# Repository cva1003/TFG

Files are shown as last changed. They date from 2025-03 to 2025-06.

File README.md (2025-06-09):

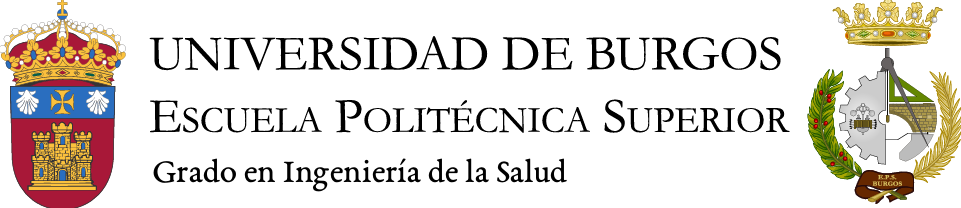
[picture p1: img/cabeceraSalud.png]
Cabecera grado

# Seguimiento clínico de pacientes con afectaciones en la mano con la ayuda de sensores de presión.
Trabajo de Fin de Grado del grado Ingeniería de la Salud de la Universidad de Burgos, realizado en el curso 2024/2025. 
A partir de este repositorio se puede observar el desarrollo del proyecto, así como los documentos con toda la información recabada y el código fuente.

## Resumen
Este proyecto se centra en la búsqueda de resolver un problema real, creando un prototipo de dispositivo e interfaz para cuantificar la fuerza que los pacientes pueden ejercer en las sesiones de terapia y establecer un registro a lo largo del tiempo de estas.

A pesar de que estos tipos de dispositivos ya existen, los hospitales públicos no están dotados de ellos debido a su alto precio y los escasos recursos en algunas áreas de los hospitales. La iniciativa de la creación de este proyecto, surge como respuesta a la necesidad comentada desde el área de terapia ocupacional. 

Se han estudiado los dispositivos que ya están en el mercado, para posteriormente realizar una búsqueda de los componentes más idóneos para el dispositivo a crear. Se ha creado un prototipo físico con sensores de fuerza resistivos y una interfaz básica para la visualización y registro de las cuantificaciones de fuerza.

### Autora: Claudia Valentín Alguacil.
### Tutor: Pedro Luis Sanchez Ortega.

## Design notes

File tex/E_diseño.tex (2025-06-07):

\apendice{Manual de especificación de diseño}
En esta sección, se detallan los planos y el diseño arquitectónico correspondientes con el desarrollo del prototipo.
\section{Planos}
En esta sección, se incluyen los planos del prototipo. 

En la \textit{Figura} \ref{fig:Vista esquemática prototipo.}, se puede observar una vista esquemática del circuito del prototipo creada mediante el programa tinkercad. 

\begin{figure}
    \centering
    
    \caption{Vista esquemática prototipo. Fuente propia}
    \label{fig:Vista esquemática prototipo.}
\end{figure}

En la \textit{Figura} \ref{fig:Circuito del prototipo}, se puede observar una vista del circuito del prototipo creada mediante el programa tinkercad. 

\begin{figure}
    \centering
    
    \caption{Circuito del prototipo. Fuente propia}
    \label{fig:Circuito del prototipo}
\end{figure}

Con estas dos figuras se pueden observar los componentes utilizados de una manera gráfica y el modo de necesario para realizar las conexiones de forma correcta.

\section{Diseño arquitectónico}

En la \textit{Figura} \ref{fig:Diagrama_flujo_arduino}, se puede observar un diagrama de flujo del proceso de lectura de los valores recogidos por los sensores de la placa Arduino. 

\begin{figure}
    \centering
    
    \caption{Diagrama flujo de la placa Arduino. Fuente propia}
    \label{fig:Diagrama_flujo_arduino}
\end{figure}

En la \textit{Figura} \ref{fig:Diagrama_de_clases}, se puede observar un diagrama de clases que representan todas las clases definidas en el archivo app.py. Este diagrama facilita la comprensión del código al mostrar las relaciones entre clases, así como los métodos contenidos en cada una de ellas.
\begin{figure}
    \centering
    
    \caption{Diagrama de clases. Fuente propia}
    \label{fig:Diagrama_de_clases}
\end{figure}

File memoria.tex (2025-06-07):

\documentclass[a4paper,12pt,twoside]{memoir}

% Castellano
\usepackage[spanish,es-tabla]{babel}
\selectlanguage{spanish}
\usepackage[utf8]{inputenc}
\usepackage[T1]{fontenc}
\usepackage{lmodern} % Scalable font
\usepackage{microtype}
\usepackage{placeins}

\RequirePackage{booktabs}
\RequirePackage[table]{xcolor}
\RequirePackage{xtab}
\RequirePackage{multirow}

% Links
\PassOptionsToPackage{hyphens}{url}\usepackage[colorlinks]{hyperref}
\hypersetup{
	allcolors = {red}
}

% Ecuaciones
\usepackage{amsmath}

% Rutas de fichero / paquete
\newcommand{\ruta}[1]{{\sffamily #1}}

% Párrafos
\nonzeroparskip

% Huérfanas y viudas
\widowpenalty100000
\clubpenalty100000

\let\tmp\oddsidemargin
\let\oddsidemargin\evensidemargin
\let\evensidemargin\tmp
\reversemarginpar

% Imágenes

% Comando para insertar una imagen en un lugar concreto.
% Los parámetros son:
% 1 --> Ruta absoluta/relativa de la figura
% 2 --> Texto a pie de figura
% 3 --> Tamaño en tanto por uno relativo al ancho de página
\usepackage{graphicx}

\newcommand{\imagen}[3]{
	\begin{figure}[!h]
		\centering
		
		\caption{#2}\label{fig:#1}
	\end{figure}
	\FloatBarrier
}

\graphicspath{ {./img/} }

% Capítulos
\chapterstyle{bianchi}
\newcommand{\capitulo}[2]{
	\setcounter{chapter}{#1}
	\setcounter{section}{0}
	\setcounter{figure}{0}
	\setcounter{table}{0}
	\chapter*{#2}
	\addcontentsline{toc}{chapter}{#2}
	\markboth{#2}{#2}
}

% Apéndices
\renewcommand{\appendixname}{Apéndice}
\renewcommand*\cftappendixname{\appendixname}

\newcommand{\apendice}[1]{
	%\renewcommand{\thechapter}{A}
	\chapter{#1}
}

\renewcommand*\cftappendixname{\appendixname\ }

% Formato de portada

\makeatletter
\usepackage{xcolor}
\newcommand{\tutor}[1]{\def\@tutor{#1}}
%\newcommand{\tutorb}[1]{\def\@tutorb{#1}}

\newcommand{\course}[1]{\def\@course{#1}}
\definecolor{cpardoBox}{HTML}{E6E6FF}
\def\maketitle{
  \null
  \thispagestyle{empty}
  % Cabecera ----------------
\begin{center}
  \noindent\vspace{1.5cm}%
\end{center}
  
  % Título proyecto y escudo salud ----------------
  \begin{center}
    \begin{minipage}[c][1.5cm][c]{.20\textwidth}
        
    \end{minipage}
  \end{center}
  
  \begin{center}
    \colorbox{cpardoBox}{%
        \begin{minipage}{.8\textwidth}
          \vspace{.5cm}\Large
          \begin{center}
          \textbf{TFG del Grado en Ingeniería de la Salud}\vspace{.6cm}\\
          \textbf{\LARGE\@title{}}
          \end{center}
          \vspace{.2cm}
        \end{minipage}
    }%
  \end{center}
  
    % Datos de alumno, curso y tutores ------------------
  \begin{center}%
  {%
    \noindent\LARGE
    Presentado por \@author{}\\ 
    en Universidad de Burgos\\
    \vspace{0.5cm}
    \noindent\Large
    \@date{}\\
    \vspace{0.5cm}
    Tutor: \@tutor{}\\ 
    %Tutores: \@tutor{} -- \@tutorb{}\\
  }%
  \end{center}%
  \null
  \cleardoublepage
  }
\makeatother
\newcommand{\nombre}{Claudia Valentín Alguacil}
\newcommand{\nombreTutor}{Pedro Luis Sanchez Ortega} 
%\newcommand{\nombreTutorb}{Tutor 2} 
\newcommand{\dni}{03951611G} 

% Datos de portada
\title{Seguimiento clínico de pacientes con afectaciones en la mano con la ayuda de sensores de fuerza}
\author{\nombre}
\tutor{\nombreTutor}
\date{\today}

\begin{document}

\maketitle

\newpage\null\thispagestyle{empty}\newpage

%%%%%%%%%%%%%%%%%%%%%%%%%%%%%%%%%%%%%%%%%%%%%%%%%%%%%%%%%%%%%%%%%%%%%%%%%%%%%%%%%%%%%%%%
\thispagestyle{empty}

\noindent\vspace{1cm}

\noindent D. \nombreTutor, profesor del departamento de Ingeniería Electromecánica, área Tecnología Electrónica.

\noindent Expone:

\noindent Que la alumna Dª. \nombre, con DNI \dni, ha realizado el Trabajo final de Grado en Ingeniería de la Salud titulado Seguimiento clínico de pacientes con afectaciones en la mano con la ayuda de sensores de fuerza. 

\noindent Y que dicho trabajo ha sido realizado por el alumno bajo la dirección del que suscribe, en virtud de lo cual se autoriza su presentación y defensa.

\begin{center} %\large
En Burgos, {\large \today}
\end{center}

\vfill\vfill\vfill

% Author and supervisor
\begin{minipage}{0.45\textwidth}
\begin{flushleft} %\large
Vº. Bº. del Tutor:\\[2cm]
D. \nombreTutor
\end{flushleft}
\end{minipage}
\hfill
\begin{minipage}{0.45\textwidth}
\begin{flushleft} %\large
%Vº. Bº. del Tutor:\\[2cm]
%D. \nombreTutorb
\end{flushleft}
\end{minipage}
\hfill

\vfill

% para casos con solo un tutor comentar lo anterior
% y descomentar lo siguiente
%Vº. Bº. del Tutor:\\[2cm]
%D. nombre tutor

\newpage\null\thispagestyle{empty}\newpage

\frontmatter

% Abstract en castellano
\renewcommand*\abstractname{Resumen}
\begin{abstract}
Este proyecto se centra en la búsqueda de resolver un problema real, creando un prototipo de dispositivo e interfaz para cuantificar la fuerza que los pacientes pueden ejercer en las sesiones de terapia y establecer un registro a lo largo del tiempo de estas.

A pesar de que estos tipos de dispositivos ya existen, los hospitales públicos no están dotados de ellos debido a su alto precio y los escasos recursos en algunas áreas de los hospitales. La iniciativa de la creación de este proyecto, surge como respuesta a la necesidad comentada desde el área de terapia ocupacional. 

Se han estudiado los dispositivos que ya están en el mercado, para posteriormente realizar una búsqueda de los componentes más idóneos para el dispositivo a crear. Se ha creado un prototipo físico con sensores de fuerza resistivos y una interfaz básica para la visualización y registro de las cuantificaciones de fuerza.
\end{abstract}

\renewcommand*\abstractname{Descriptores}
\begin{abstract}
Sensor de Fuerza Resistivo, terapia ocupacional, cuantificación, fuerza, dinamómetro , mano, Arduino, bajo coste.
\ldots
\end{abstract}

\clearpage

% Abstract en inglés
\renewcommand*\abstractname{Abstract}
\begin{abstract}
This project focuses on searching for a real issue by creating a prototype device and interface to quantify the strength that patients can apply during therapy sessions, and to establish a record of these measurements over time.

Despite similar devices already existing, many public hospitals often are not equipped with them due to their high cost and the limited resources available in some certain hospital departments. 
The initiative for this project arose in response to an actual need expressed by the occupational therapy department.

Research has been conducted on the devices currently available on the market, followed by an investigation on potential components that could be used to build a new device. A physical prototype has been developed using force sensing resistors, along with a basic interface for visualizing and recording the strength measurements.
\end{abstract}

\renewcommand*\abstractname{Keywords}
\begin{abstract}
Force sensing resistors, occupational therapy, quantification, strength, hand, dinamometer, Arduino, low cost.
\end{abstract}

\clearpage

% Indices
\tableofcontents

\clearpage

\listoffigures

\clearpage

\listoftables
\clearpage

\mainmatter
\include{./tex/1_introduccion}
\include{./tex/2_objetivos}
\include{./tex/3_teorico}
\include{./tex/4_DicusiónClinica}
\include{./tex/5_metodologia}
\include{./tex/6_resultados}
\include{./tex/7_conclusiones}
\include{./tex/8_lineas_futuras}

\bibliographystyle{apalike}
\bibliography{bibliografia}

\end{document}

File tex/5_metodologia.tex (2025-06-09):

\capitulo{5}{Metodología}

\section{Descripción de los Datos}
Para la realización del proyecto, no se han utilizado datos predefinidos por bases de datos, APIs públicas u otras fuentes de información. Los datos que aparecen son los obtenidos por los sensores durante las pruebas del dispositivo.
\section{Técnicas metodológicas de programación}
En esta sección se detallan las técnicas metodológicas de programación empleadas en el desarrollo del proyecto. Para detalles técnicos sobre bibliotecas específicas y estructura del proyecto, véase Apéndices B.1 y C.1 del anexo técnico.

\subsection{Lenguajes de programación}
En el proyecto se emplearon los siguientes lenguajes de programación especialmente seleccionados para cumplir con los requisitos de este.
\subsubsection{\textit{C++}}
Lenguaje de programación compilado y multiparadigma, caracterizado por su enfoque imperativo y orientado a objetos. Además, incluye el uso de programación general y funcional.
Muy utilizado en la creación de programas para la creación de interfaces y videojuegos.\cite{C++}\footnote{Página web con información de C++\cite{C++}.}

Se ha utilizado este lenguaje para la implementación de toda la lógica asociada a la placa Elegoo.
\subsubsection{\textit{Python}}
Python es un lenguaje alto de programación altamente usado, interpretado y multiplataforma. Diseñado para ser fácil de leer y escribir.
Ampliamente utilizado en el desarrollo web, ciberseguridad, aprendizaje automático, desarrollo de aplicaciones o la automatización de tareas, entre muchas otras aplicaciones.\cite{Python}\footnote{Página web con información de Python\cite{Python}.}
\subsubsection{\textit{Bash}}
Bash es un lenguaje de comandos y shell de Unix/Linux, también conocido como shell scripting o comandos de terminal.
Se ejecuta en una terminal o ventana de texto. \cite{Bash}\footnote{Página web con información de Bash\cite{Bash}.}

En este proyecto ha sido utilizado en la terminal de Rstudio para la creación de archivos, actualización de GitHub entre otras tareas.

\subsection{Bibliotecas}
Las bibliotecas o librerías son un conjunto de funciones, clases y recursos ya escritos que se pueden utilizar de manera libre para agilizar procesos. 
\subsubsection{json}
Librería que permite la edición y adición de documentos JSON.
\subsubsection{os}
Librería que permite la interacción con el sistema operativo.
\subsubsection{pandas}
Librería que permite el análisis y manipulación de datos.
\subsubsection{openpyxl}
Librería que permite leer, modificar y escribir archivos excel.
\subsubsection{Kivy}
Librería que permite la creación de interfaces gráficas de usuario(GUI).\cite{kivy}\footnote{Página web con información de kivy y documentación\cite{kivy}.}
\cite{KivyMD}\footnote{Página web con información y documentación de kivyMD, una extensión de Kivy\cite{KivyMD}.}
\subsubsection{cryptography}

Liberia que permite encriptar y desencriptar palabras, frases o documentos. \cite{ruh_encriptar_2023}\footnote{Blog donde explican el funcionamiento de cryptography y como encriptar archivos\cite{ruh_encriptar_2023}.}

Utilizada para encriptar los archivos que recogen datos sensibles de pacientes o personal sanitario. En el archivo \href{https://github.com/cva1003/TFG/blob/main/Aplicaci%C3%B3nEscritorio/cifrar.py} {cifrar.py} se encuentra el código utilizado para cifrar los documentos, este código además se encuentra en \href{https://github.com/cva1003/TFG/blob/main/Aplicaci%C3%B3nEscritorio/app.py} {app.py} para descifrar los documentos justo al abrirse el desplegable y cifrarlos al cerrarlo.
\section{Entornos y aplicaciones}
En esta sección voy a realizar una recopilación de aplicaciones y entornos que he utilizado para la realización del proyecto, todas ellas explicadas y utilizadas en diferentes asignaturas del grado. El entorno de desarrollo y la estructura de archivos se describen con mayor detalle en el Apéndice C.1 del anexo.
\subsection{Overleaf}
El Overleaf es una herramienta en línea que permite redactar, editar, exportar y compartir con otros usuarios documentos científicos en formato LaTeX.

En este proyecto, se utiliza Overleaf para la creación de este documento y el anexo.
\subsection{RStudio}
RStudio es un entorno de software libre para computación estadística y gráficos. Tiene la capacidad de ejecutarse y compilarse en una amplia variedad de plataformas como Linux, MAC y Windows.\cite{Rstudio}\footnote{Página web con información de Rstudio\cite{Rstudio}.}

En este proyecto, se utiliza RStudio para realizar una unión entre el repositorio de GitHub y la carpeta de mi escritorio del ordenador donde voy avanzando el proyecto.
\subsection{GitHub}
GitHub es una plataforma basada en la nube cuya finalidad es almacenar, compartir y trabajar en conjunto con otros usuarios. 
Además, permite tener un seguimiento del trabajo, lo que permite ver todas las versiones que se van realizando de este mismo.\cite{GitHub}\footnote{Página web de GitHub\cite{GitHub}.} 

En este proyecto, GitHub se ha utilizado para realizar un seguimiento del proyecto, permitiendo que tanto el tutor como los miembros del tribunal puedan visualizar los cambios realizados y participar activamente en el proceso.
\subsection{Tinkercad}
Tinkercad es una aplicación web que permite la realización de diseños en 3D, la realización de circuitos y la posibilidad de escribir programas para dar vida a los diseños mediante la codificación.

En este proyecto, ha sido utilizada para la realización de la simulación del diseño del circuito electrónico, ya que permite utilizar diseños electrónicos ya hechos, modificarlos, añadir más componentes o comenzar a diseñar un circuito desde el inicio.
\subsection{Visual Studio Code}
Visual Studio Code es una aplicación que funciona como editor de código fuente, personalizable y multiplataforma.
Permite al usuario la creación y edición de archivos en múltiples lenguajes y formatos, desde texto plano hasta YAML, pasando por JSON, Markdown, XML y muchos otros. Además, gracias a sus múltiples extensiones, permite, entre otras cosas, el control de versiones con la extensión de GitHub o incluso el uso de IA con la extensión de Copilot.

En este proyecto, ha sido utilizada para realizar la interfaz y establecer la comunicación con la placa Elegoo, la elección de este editor se debió a las características mencionadas anteriormente, la facilidad de uso y la versatilidad, permitiendo un desarrollo ágil y eficiente del proyecto.
\subsection{Freecad}
Freecad es una aplicación multiplataforma, de código abierto y completamente gratuita, que permite al usuario crear diseños en tres dimensiones.
Es un modelador 3D paramétrico de código abierto, permitiendo así diseños lo más próximos a la realidad.

En este proyecto, ha sido utilizada para realizar un modelo 3D para el proyecto.\cite{freecad}\footnote{Página web con información y posibilidad de descarga de freecad\cite{freecad}.} 
\subsection{ChatGPT}
Chat GPT es una inteligencia artificial.

En este proyecto, ha sido utilizada para la creación del logo y la solución de errores que iban surgiendo en el desarrollo del desplegable.
\section{Herramientas}
En esta sección voy a exponer y explicar las herramientas que he utilizado en el proyecto. Los planos y diagramas de conexiones pueden consultarse en el Apéndice E del anexo.
\subsection{Placa de Elegoo uno R3}
Placa de Arduino es una placa de desarrollo de código abierto. 
Integra el microcontrolador chip Atmel ATMEGA+328P principal y un ATmega16U2 para la comunicación con USB. \cite{Elegoo}\footnote{Página web con información de placa Elegoo\cite{Elegoo}.}

Está formado con 14 pines digitales, 6 pines analógicos, 5 pines de energía, un puerto de USB para la conexión con el ordenador, un conector para la alimentación, un botón de reinicio,un resonador de cerámica de 16 MHz, leds indicadores y los puertos I2C y SPI.\cite{Arduino}\footnote{Página web con información de Arduino\cite{Arduino}.}

En la \textit{Figura \ref{fig:Placa Elegoo}} se puede ver una imagen del componente.
\begin{figure}[h]
        \centering
        
        \caption{Placa Elegoo. Fuente propia}
        \label{fig:Placa Elegoo}
    \end{figure}

\subsection{Cables Dupont}
Los cables Dupont son alambres de un metal conductor recubiertos de un plástico aislante flexible que permiten las conexiones entre los propios componentes de la protoboard o entre la protoboard y la placa de Elegoo. 

En la \textit{Figura \ref{fig:cable_dupont}} se puede ver una imagen del componente.
\begin{figure}[h]
        \centering
        
        \caption{Cables. Fuente propia}
        \label{fig:cable_dupont}
    \end{figure}
   
\subsection{Cable USB}
El cable USB es un cable conector que une la placa Elegoo con el ordenador, permite introducir las instrucciones programadas en el ordenador en placa Elegoo. 

En la \textit{Figura \ref{fig:Cable USB}} se puede ver una imagen del componente.
\begin{figure}[h]
        \centering
        
        \caption{Cable USB. Fuente propia}
        \label{fig:Cable USB}
    \end{figure}
   
\subsection{Resistencias}
Las resistencias son componentes electrónicos que limitan el flujo de la energía eléctrica en el circuito, son una medida de la oposición al flujo de corriente.  \cite{Resistencia}\footnote{Página web con información de las resistencias\cite{Resistencia}.}

En la \textit{Figura \ref{fig:Resistencias}} se puede ver una imagen del componente.
\begin{figure}[h]
        \centering
        
        \caption{Resistencia. Fuente propia}
        \label{fig:Resistencias}
    \end{figure}
    
\subsection{Protoboard}
La protoboard o también llamada placa de pruebas, permite la creación de circuitos electrónicos. Es una matriz con orificios interconectados que permiten la inserción de componentes eléctricos. 

En la \textit{Figura \ref{fig:Protoboard} } se puede ver una imagen del componente.
\begin{figure}[h]
        \centering
        
        \caption{Protoboard. Fuente propia}
        \label{fig:Protoboard}
    \end{figure}

\subsection{Pin Botón}
El pin botón es un dispositivo de entrada que, al ser pulsado, cambia el estado del pin digital, permitiendo que el programa detecte y haga acciones cuando el usuario pulse el botón.

En la \textit{Figura} \ref{fig:pinBoton}, se puede ver una imagen del componente.

\begin{figure}[h]
        \centering
        
        \caption{pin Botón. Fuente propia}
        \label{fig:pinBoton}
    \end{figure}
\subsection{Luz led}
La luz Led es un componente eléctrico, que al aplicarle corriente emite luz.

En la \textit{Figura} \ref{fig:LuzLed}, se puede ver una imagen del componente.

\begin{figure}[h]
        \centering
        
        \caption{Luz led. Fuente propia}
        \label{fig:LuzLed}
    \end{figure}
    
\subsection{Posibles sensores}
En esta subsección se presentarán los sensores investigados para la realización del proyecto, el sensor seleccionado y el porqué de su selección.
\subsubsection{\textit{{Sensor fuerza resistivo}}}
Los sensores de fuerza resistivos son sensores capaces de detectar la presión o fuerza que se les ejerce.
Como su propio nombre dice, necesita para su uso una resistencia, la cual actúa como divisor de voltaje.
\subsubsection{\textit{{Células de carga}}}
Las células de carga son herramientas muy utilizadas en la industria para las mediciones de fuerza, compresión y tensión.
Son un tipo de transductores que convierten la fuerza aplicada  en una señal eléctrica medible. \cite{Celula_Carga}\footnote{Página web con información sobre las células de carga\cite{Celula_Carga}.}
Existen múltiples tipos de los cuales destacamos los siguientes:
    \begin{itemize}
        \item Células de cargas mecánicas: dispositivo que mide la fuerza mecánica al aplicarle un objeto, miden pesos.
        \item Células de carga extensométricas: dispositivo que mide deformaciones locales según su posición. La medida de la fuerza es determinada por la integración de los valores de cada valor individual, formado por un transductor de fuerza y un elemento elástico.\cite{celulas_extensométricas}\footnote{Página web con información de las células de carga de tipo extensométricas\cite{celulas_extensométricas}.}
        \item Células de carga hidráulicas: dispositivo llenó de un líquido con tiene una presión de precarga, al aplicar la fuerza aumenta la presión del líquido que es medida por un transductor de presión.
        \cite{Celulas_hidraulicas}\footnote{Página web con información de las células de carga de tipo hidraulicas\cite{Celulas_hidraulicas}.}
        \item Células de carga piezoeléctricas: dispositivo que mide fuerzas dinámicas o cuasiestáticas, tanto de tracción como compresión. Muy sensibles y rápidas.
        \cite{Celulas_piezoelectricas}\footnote{Página web con información de las células de carga de tipo piezoélectricas \cite{Celulas_piezoelectricas}.}
    \end{itemize}
En la \textit{tabla \ref{tab:comparacion_sensores}} se realiza un resumen donde se expondrán el tipo, características y precio aproximado de cada una de ellas.
\begin{table}[h]
    \begin{tabular}{|p{4cm}|p{8cm}|p{1.5cm}|}
    \rowcolor[HTML]{BFBFBF} 
    \hline
    \textbf{Tipo} & \textbf{Características de medición} & \textbf{Precio} \\    \hline
    Células de carga mecánica & Rango de medición limitado, respuesta lenta, bajo costo, bajo mantenimiento & 10-200€ \\    \hline
    Células de carga extensiométricas & Rango amplio (hasta 50 kN o más), buena precisión, alta estabilidad & 30-200€ \\    \hline
    Células de carga hidráulicas & Medición de fuerzas grandes (hasta 100 kN), sin electrónica, resistente a ambientes hostiles & 50-300€ \\    \hline
    Células de carga piezoeléctrica & Rango de aproximadamente de 10 N a 300 kN, de precisión muy alta, ideal para fuerzas dinámicas & 60-500€ \\    \hline
    Sensor de fuerza resistivo & Rango de aproximadamente de 0-300N, precisión alta y de pequeño tamaño & 7-30€ \\ \hline
    \end{tabular}
    \caption{Tabla de comparación de sensores de fuerza}
    \label{tab:comparacion_sensores}
\end{table}

Tras comparar los distintos sensores según su precio, características e integración, he concluido que los sensores de fuerza resistivos son la mejor opción para llevar a cabo el proyecto.

\subsection{{Sensor de fuerza resistivo}}
Como se ha explicado anteriormente, los sensores de fuerza resistivos son sensores capaces de medir la fuerza ejercida con el uso de resistencias.

Para el proyecto se ha utilizado el sensor MD30-60 capaz de medir de 0 a 30Kg. 

\begin{figure}[h]
        \centering
        
        \caption{Sensor de fuerza MD30-60. Fuente propia}
        \label{fig:Sensor de fuerza}
\end{figure}

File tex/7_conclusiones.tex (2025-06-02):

\capitulo{7}{Conclusiones}

Concluido el desarrollo integral del proyecto, se presentan las principales conclusiones obtenidas del trabajo realizado:

\begin{itemize}
    \item El sensor de fuerza resistivo seleccionado cumple con los requisitos esperables, siendo favorable su utilización como método de cuantificación, con un promedio de error de 4.6\%.
    \item El diseño de los prototipos, tanto físico como de software, cumplen con los requisitos planteados. 
    \item Actualmente, no existe un dispositivo de bajo coste en el mercado que realice esta tarea, por lo que mejorar el diseño propuesto puede abrir una oportunidad dentro del mercado tecnológico-sanitario.
\end{itemize}

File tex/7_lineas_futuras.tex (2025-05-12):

\capitulo{6}{Lineas Futuras}
Al tratarse de un prototipo, se pueden realizar varias mejoras para llegar a un dispositivo comerciable , robusto y de bajo coste.

Una de las primeras mejoras que podría implementarse es la eliminación del botón físico del dispositivo destinado a inicio de la medición, de manera que esta se active directamente al presionar 'Iniciar medición' en la interfaz. 

Asimismo, se podrían diseñar diferentes tipos de mangos donde poner los sensores, variando tanto en tamaño como en los materiales a utilizar. Debido a que el medio utilizado es impresión 3D, las posibilidades de personalización son muy amplias. Se podría utilizar material semielástico, permitiendo así una leve deformación, ya que estos materiales combinan flexibilidad y resistencia. Otra posibilidad, podría ser emplear compuestos como mezclas de PLA con polvo metálico, que aportarían mayor rigidez y peso, lo que supondría un desafío adicional durante el ejercicio.

De otra manera, se puede emplear un cambio en el tamaño ajustando el diámetro del mango, lo que permite la adaptación en el agarre a las necesidades especificas de cada persona. Contar con estos diferentes diámetros facilita el agarre para las personas según las diferentes patologías que puedan afectar la movilidad o fuerza de la mano.

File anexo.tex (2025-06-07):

\documentclass[a4paper,12pt,twoside]{memoir}

% Castellano
\usepackage[spanish,es-tabla]{babel}
\selectlanguage{spanish}
\usepackage[utf8]{inputenc}
\usepackage[T1]{fontenc}
\usepackage{lmodern} % scalable font
\usepackage{microtype}
\usepackage{placeins}

\RequirePackage{booktabs}
\RequirePackage[table]{xcolor}
\RequirePackage{xtab}
\RequirePackage{multirow}

% Links
\PassOptionsToPackage{hyphens}{url}\usepackage[colorlinks]{hyperref}
\hypersetup{
	allcolors = {red}
}

% Ecuaciones
\usepackage{amsmath}

% Rutas de fichero / paquete
\newcommand{\ruta}[1]{{\sffamily #1}}

% Párrafos
\nonzeroparskip

% Huérfanas y viudas
\widowpenalty100000
\clubpenalty100000

% Evitar solapes en el header
\nouppercaseheads

\let\tmp\oddsidemargin
\let\oddsidemargin\evensidemargin
\let\evensidemargin\tmp
\reversemarginpar

% Imagenes
\usepackage{graphicx}
\newcommand{\imagen}[2]{
	\begin{figure}[!h]
		\centering
		
		\caption{#2}\label{fig:#1}
	\end{figure}
	\FloatBarrier
}

\graphicspath{ {./img/} }

% Capítulos
\chapterstyle{bianchi}
\newcommand{\capitulo}[2]{
	\setcounter{chapter}{#1}
	\setcounter{section}{0}
	\setcounter{figure}{0}
	\setcounter{table}{0}
	\chapter*{#2}
	\addcontentsline{toc}{chapter}{#2}
	\markboth{#2}{#2}
}

% Apéndices
\renewcommand{\appendixname}{Apéndice}
\renewcommand*\cftappendixname{\appendixname}

\newcommand{\apendice}[1]{
	%\renewcommand{\thechapter}{A}
	\chapter{#1}
}

\renewcommand*\cftappendixname{\appendixname\ }

% Formato de portada
\makeatletter
\usepackage{xcolor}
\newcommand{\tutor}[1]{\def\@tutor{#1}}
%\newcommand{\tutorb}[1]{\def\@tutorb{#1}}
\newcommand{\course}[1]{\def\@course{#1}}
\definecolor{cpardoBox}{HTML}{E6E6FF}
\def\maketitle{
  \null
  \thispagestyle{empty}
  % Cabecera ----------------
\begin{center}
  \noindent\vspace{1.5cm}%
\end{center}
  
  % Título proyecto y escudo salud ----------------
  \begin{center}
    \begin{minipage}[c][1.5cm][c]{.20\textwidth}
        
    \end{minipage}
  \end{center}
  
  \begin{center}
    \colorbox{cpardoBox}{%
        \begin{minipage}{.8\textwidth}
          \vspace{.5cm}\Large
          \begin{center}
          \textbf{TFG del Grado en Ingeniería de la Salud}\vspace{.6cm}\\
          \textbf{\LARGE\@title{}}
          \end{center}
          \vspace{.2cm}
        \end{minipage}
    }%
  \end{center}
  
    % Datos de alumno, curso y tutores ------------------
  \begin{center}%
  {%
    \noindent\LARGE
    Presentado por \@author{}\\ 
    en Universidad de Burgos\\
    \vspace{0.5cm}
    \noindent\Large
    \@date{}\\
    \vspace{0.5cm}
    Tutor: \@tutor{}\\ % comenta el que no corresponda
    %Tutores: \@tutor{} -- \@tutorb{}\\
  }%
  \end{center}%
  \null
  \cleardoublepage
  }
\makeatother

% Datos de portada
\title{Seguimiento clínico de pacientes con afectaciones en
la mano con la ayuda de sensores de fuerza\\Documentación Técnica}
\author{Claudia Valentín Alguacil}
\tutor{Pedro Luis Sánchez Ortega}
%\tutorb{nombre tutor 2}
\date{\today}

\begin{document}

\maketitle

\cleardoublepage

%%%%%%%%%%%%%%%%%%%%%%%%%%%%%%%%%%%%%%%%%%%%%%%%%%%%%%%%%%%%%%%%%%%%%%%%%%%%%%%%%%%%%%%%

\frontmatter

\clearpage

% Indices
\tableofcontents

\clearpage

\listoffigures

\clearpage

\listoftables

\clearpage

\mainmatter

\appendix

\include{./tex/A_planificacion}
\include{./tex/B_manual_usuario}
\include{./tex/C_manual_programador}
\include{./tex/D_datos}
\include{./tex/E_diseno}
\include{./tex/F_requisitos}
\include{./tex/G_experimental}
\include{./tex/H_ODS}

\bibliographystyle{apalike}
\bibliography{bibliografiaAnexos}

\end{document}

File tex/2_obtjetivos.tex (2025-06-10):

\capitulo{2}{Objetivos}
En este apartado se aborda la exposición de los objetivos principales del proyecto, los cuales van a definir el desarrollo y orientación de este.
\section{Objetivos del proyecto}
\begin{itemize}
    \item Estudiar los dispositivos actuales destinados a la medida de presión de mano.
    \item Identificar y examinar dispositivos o sensores disponibles en el mercado que puedan ser útiles en el proyecto.
    \item Crear de uno o más prototipos de un dispositivo que pueda medir la presión ejercida por la mano.
    \item Desarrollar de un prototipo de interfaz que permita la visualización y almacenamiento de resultados.
\end{itemize}
\section{Objetivos personales}
\begin{itemize}
    \item Emplear arduino y LaTeX para realizar el proyecto. 
    \item Usar Github como plataforma de seguimiento e ir subiendo los avances realizados.
    \item Desarrollar un prototipo versátil y práctico, que en caso de no estar completamente finalizado, pueda ser mejorado optimizando y mejorando su funcionalidad.
    \item Analizar costes y viabilidad del proyecto.  
\end{itemize}

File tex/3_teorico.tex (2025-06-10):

\capitulo{3}{Conceptos teóricos}
\section{Conceptos teóricos básicos}
Para facilitar la comprensión del proyecto, he seleccionado una serie de conceptos útiles a definir. 
\begin{itemize}
    \item Dinamómetro: aparato destinado a la medición de la fuerza y el peso de los objetos a partir de la elasticidad de un resorte o muelle elástico.\cite{Dinamometro}
    \item Terapia ocupacional: profesión socio-sanitaria que se enfoca en ayudar a las personas a desarrollar, recuperar o mantener la capacidad para realizar actividades cotidianas y ocupaciones significativas. \cite{T.O}\footnote{Página web con información sobre la terapia ocupacional\cite{T.O}.}
    \item Transductor: dispositivo al que se aplica una energía de entrada y devuelve una energía de salida. \cite{celulas_extensométricas}
    \item Relación lineal: tendencia en los datos que se puede modelar mediante una línea recta, es decir ambas variables aumentan o disminuyen simultáneamente a un ritmo constante. \cite{Relación_lineal}
    \item Fatiga Muscular: incapacidad para seguir generando un nivel de fuerza o una intensidad de ejercicio determinada. \cite{gomez_campos_mecanismos_2010}
    \item Sensor de Fuerza Resistivo (FSR): dispositivo capaz de detectar la presión o fuerza que se les ejerce. Como su propio nombre dice, necesita para su uso una resistencia, la cual actúa como divisor de voltaje
    \item Tabla canadiense: instrumento de mecanoterapia que se utiliza en el tratamiento y rehabilitación de lesiones de la mano \ref{fig:tabla canadiense}\cite{cantero_tellez_terapia_2020}.
    \begin{figure}
        \centering
        
        \caption{Tabla canadiense. Fuente tablacanadiense.es}
        \label{fig:tabla canadiense}
    \end{figure}
\end{itemize}
\section{Estado del arte.}

El proyecto ha de comenzar con búsqueda en el panorama actual en la medida de fuerza. 

En esta subsección se analiza y sintetiza el conocimiento existente en el área específica del proyecto. El objetivo principal es situar el trabajo dentro de un marco teórico y tecnológico, analizando investigaciones previas, aportes y detectando problemas que se puedan resolver.
\subsection{Dinamómetros}
En la actualidad, los dinamómetros son una de las herramientas más utilizadas  para la medida de fuerza de los pacientes durante las sesiones de terapia ocupacional, fisioterapia o medicina deportiva. Existen diferentes modelos en el mercado que se diferencian en precisión, tecnología, precio o aplicación. 
A continuación, he destacado algunos de ellos:
\begin{itemize}
    \item Activforce 2: Es un dispositivo portátil e inalámbrico creado por la empresa estadounidense Activforce, con sede en California. Combina un dinamómetro con un inclinómetro lo que permite medir la fuerza máxima, promedio, rango de movimiento y simetría derecha-izquierda tanto en fuerza como en movimiento. Todas las mediciones se registran en una aplicación compatible con Android e iOS, donde el usuario puede ver toda la información recabada por el dispositivo.\cite{activforce}\footnote{Página web del dinamómetro Activforce2 con la información general del producto \cite{activforce}.}
    
    En la \textit{Figura} \ref{fig:activforce} se puede ver una imagen del producto.
    \begin{figure}[h]
        \centering
        
        \caption{Dispositivo ActivForce2. Fuente activforce.com}
        \label{fig:activforce}
    \end{figure}
    
    Además, el Activforce 2 incluye varios accesorios que facilitan su uso en diferentes partes del cuerpo, permitiendo la ejecución de una amplia variedad de ejercicios y evaluaciones. Es un dispositivo de compra libre cuyo precio ronda los 450€. En la \textit{Figura} \ref{fig:activforce_Attachments} se puede ver una imagen del producto y los accesorios.
    \begin{figure}[h]
        \centering
        
        \caption{Accesorios compatibles con el dispositivo ActivForce2. Fuente activforce.com}
        \label{fig:activforce_Attachments}
    \end{figure}

    \item MicroFET 2: Es un dispositivo portátil e inalámbrico creado por la empresa belga MVS in motion. Es un dinamómetro diseñado para la evaluación y prueba de fuerza permite tomar mediciones de prueba muscular objetivas, cuantificables y confiables. 
    Es utilizado para la ayuda en el diagnóstico, pronóstico y el tratamiento de trastornos musculares. Presenta una pantalla digital donde se puede observar el valor de las mediciones en tiempo real. \cite{microfet}\footnote{Página web del dinamómetro MicroFET2 con la información general del producto \cite{microfet}.}
    Es un dispositivo de compra libre cuyo precio ronda los 1200€. 
    
    En la \textit{Figura} \ref{fig:MicroFET 2} se puede ver una imagen del dispositivo.
    \begin{figure}[h]
        \centering
        
        \caption{Dispositivo MicroFET 2. Fuente fysiosupplies.es}
        \label{fig:MicroFET 2}
    \end{figure}
    
    \item MAP 80K1S: Es un dispositivo portátil e inalámbrico creado por la empresa alemana KERN \& SOHN. Es un dinamómetro de mano utilizado específicamente para tratamientos de rehabilitación, para la determinación de la fuerza de cierre de mano.
    Presenta cuatro modos de medición: tiempo real, valor máximo. valor promedio y de contaje. 
    Es utilizado en sesiones de rehabilitación para detectar la disminución de fuerza y la evolución del paciente entre sesiones. Cuenta con una pantalla digital donde se puede observar las mediciones realizadas. 
    Es un dispositivo de compra libre cuyo precio ronda los 280€. \cite{Map80k1s}\footnote{Página web del dinamómetro Map80K1S con la información general del producto \cite{Map80k1s}.}
    
    En la \textit{Figura} \ref{fig:Dispositivo MAP 80K1S} se puede ver una imagen del dispositivo.
      \begin{figure}[h]
        \centering
        
        \caption{Dispositivo MAP 80K1S. Fuente kern-sohn.com}
        \label{fig:Dispositivo MAP 80K1S}
    \end{figure}
    
    \item Squeezy dynamometer: Es un dispositivo portátil, un dinamómetro de presión hidráulica de mano cuya medición se realiza apretando la perilla, generando presión que se transfiere al calibrador, el cual muestra con precisión la fuerza ejercida. Es un dispositivo de compra libre cuyo precio ronda los 70 €. \cite{SqueezeDinamometro}\footnote{Página web del dinamómetro Squeezy con la información general del producto \cite{SqueezeDinamometro}.} 
    
    En la \textit{Figura \ref{fig:Dinamómetro de Pera}} se puede ver una imagen del dispositivo.
    \begin{figure}[h]
        \centering
        
        \caption{Dinamómetro de Pera. Fuente rehabmedic.com}
        \label{fig:Dinamómetro de Pera}
    \end{figure}
\end{itemize}
\subsection{Artículos relacionados}
La cuantificación de la fuerza en las manos  y su posterior análisis, es un tema que ya ha sido tratado por otros equipos de investigación en varios países. 

En esta subsección presentaré los artículos que he encontrado relacionados con el área, abarcando tanto la creación de dispositivos para la medición de la fuerza como el uso de dinamómetros para el registro de la evolución de los pacientes.
\begin{itemize}
    \item \textbf{Dispositivo de medición de fuerza de los dedos y su
rol en el seguimiento de las funciones de la mano}

Juliana Gomez et al, en su artículo llamado 'Dispositivo de medición de fuerza de los dedos y su rol en el seguimiento de las funciones de la mano' publicado en la revista de cirugía plástica Ibero Latinoamericana aborda la creación de un dispositivo capaz de medir la fuerza de los dedos de manera individual, para su uso en la evaluación del paciente sano y de pacientes con patologías traumáticas y no traumáticas, para determinar grados de discapacidad, seguimiento de enfermedades y/o recuperaciones. 
Este dispositivo se basa en el uso de 5 sensores del tipo Flexiforce A301 de la empresa TESKA®, sistema embebido
tipo Arduino y Matlab, se puede observar en la \textit{Figura \ref{fig:Dinamómetro creado por Juliana Gomez}}. Además, afirman la validez de su uso tras realizar un estudio con veinte sujetos sanos, obteniendo tasas de medición equiparables a las de otros sistemas. \cite{GOMEZ2022}\footnote{Artículo de la creación de un dispositivo con sensores de fuerza\cite{GOMEZ2022}.}
    \begin{figure}[h]
        \centering
        
        \caption{Dinamómetro creado por Juliana Gomez. Fuente scielo.isciii.es}
        \label{fig:Dinamómetro creado por Juliana Gomez}
    \end{figure}
\item \textbf{Uso del dinamómetro para mejorar la fuerza de la mano del adulto mayor.}
    
Mayra Lasteña Millingalli Ortega et al, en su artículo de revisión llamado 'Uso del dinamómetro para mejorar la fuerza de la mano del adulto mayor' publicado en la Revista Científica Arbitrada Multidisciplinaria PENTACIENCIAS en Octubre de 2023, realizan un trabajo de investigación revisando artículos en inglés y español publicados entre 2013 y 2022.
La población de estudio son pacientes geriátricos tratados en Terapia Ocupacional, las investigadoras exponen que actualmente en estas sesiones de terapia los pacientes son evaluados mediante métodos manuales como las escalas de registros, afirman que estos métodos son rudimentarios y no evidentes. \cite{Articulo_din}\footnote{Artículo que habla sobre el uso del dinamómetro\cite{Articulo_din}.}
\item \textbf{Diseño de dinamómetro con enfoque al monitoreo de fuerza de agarre de mano, en la 'Clínica Niño Sano' de niños quemados.}

    Tesis realizada en la universidad de Guatemala por Luis Carlos Ralon Gordillo en 2019, alumno del grado de  Ingeniería Mecatrónica. 

    Su tesis se fundamenta en la creación de un dispositivo para el monitoreo de la recuperación de la fuerza motriz de niños con quemaduras de tercer grado en la mano, utilizando un sensor de fuerza resistiva y un  microcontrolador PIC 16F88.

    En la \textit{Figura} \ref{fig:Prototipo dinamómetro Luis} se puede observar el prototipo realizado por el alumno.

    En el Luis Carlos Ralon afirma el correcto funcionamiento de su dispositivo, teniendo el sensor un  error promedio de 5.50 \%. \cite{ralon_gordillo_diseno_2019}

    \begin{figure}
        \centering
        
        \caption{Prototipo dinamómetro Luis Carlos Ralon. Fuente Universidad del Valle de Guatemala }
        \label{fig:Prototipo dinamómetro Luis}
    \end{figure}    
\end{itemize}

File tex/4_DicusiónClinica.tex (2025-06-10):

\capitulo{4}{Discusión clínica.}
\section{Justificación clínica del problema.}

Para comprender bien la necesidad de crear un nuevo dispositivo, seleccionar los componentes adecuados que lo formen y entender su funcionamiento, se ha de conocer la compleja estructura de la mano y las patologías más comunes que pueden presentarse. 

En esta sección se va a exponer la fisiología de la mano humana y algunas patologías que afectan a su correcto funcionamiento.
\subsection{Fisiología de la mano.}

La mano es una estructura anatómica compleja, formada por cuatro sistemas, el sistema muscular, el sistema óseo, el sistema nervioso y el sistema articular. 

\subsubsection{Sistema muscular}

El sistema muscular de la mano está formado por dos grupos principales de músculos, los extrínsecos y los intrínsecos, que proporcionan la movilidad a la mano. 

Los músculos extrínsecos, son los músculos del antebrazo que se insertan en la mano, como el extensor radial largo del carpo. Los músculos intrínsecos son todos aquellos cuyos orígenes e inserciones están ubicadas en la región mano-muñeca, están subdivididos en cinco grupos tenares, hipotenares, lumbricales, interóseos palmares e dorsales.\cite{mano_anatomía}

En la \textit{Figura} \ref{fig:Músculos_mano}, se pueden observar los músculos intrínsecos.
\begin{figure}
    \centering
    
    \caption{Músculos intrínsecos de mano. Fuente mirandafisioterapia.com}
    \label{fig:Músculos_mano}
\end{figure}

\subsubsection{Sistema óseo}
La mano está formada por 27 huesos, divididos en 3 grupos principales: huesos del carpo, huesos del metacarpo y falanges de la mano.

Los huesos del carpo están dispuestos en dos filas distintas formando la muñeca, fila proximal (escafoides, semilunar, piramidal y pisiforme) y fila distal (trapecio, trapezoide, grande y ganchoso). \cite{mano_anatomía}

En la \textit{Figura} \ref{fig:Huesos_mano}, se pueden observar los 27 huesos que forman la mano.
\begin{figure}
    \centering
    
    \caption{Huesos de la mano. Fuente didactalia.net}
    \label{fig:Huesos_mano}
\end{figure}
\subsubsection{Sistema nervioso}

Los nervios de la mano y la muñeca se originan en el plexo braquial, son los nervios medianos, ulnar (cubital) y radial\cite{mano_anatomía}:
\begin{itemize}
    \item Mediano: atraviesa el túnel carpiano, responsable de la movilidad y sensibilidad de la palma y de los dedos anular, corazón, pulgar e índice.
    \item Ulnar: entra por los músculos flexores, responsable de la movilidad y sensibilidad de los músculos constrictores de la mano y de los dedos meñique y anular.
    \item Radial: responsable de la sensibilidad de la mano.

En la \textit{Figura} \ref{fig:nervios de la mano}, podemos observar el recorrido y situación de los nervios desde el plexo braquial hasta la mano.
\begin{figure}
    \centering
    
    \caption{Nervios de la mano. Fuente kenhub.com}
    \label{fig:nervios de la mano}
\end{figure}
\end{itemize}
\subsubsection{Sistema articular}

El sistema articular de la mano, son todas las articulaciones que comprenden desde la muñeca hasta las falanges. 

Las articulaciones entre el carpo y el metacarpo son las carpometacarpianas. Las articulaciones entre los metacarpos y las falanges proximales son las articulaciones metacarpofalángicas. Las articulaciones entre las falanges son las articulaciones interfalángicas - proximal y distal. \cite{huesos_mano}
\subsection{Patologías que afectan a las manos.}

Según lo expuesto por \cite{arroyo-berezowsky_epidemiology_2021}, entre el 6.6\% y el 28.6\% de las lesiones del sistema musculoesquelético son causadas en las manos.

En 2009 en Estados Unidos se trataron cerca de 100.000 lesiones en los miembros superiores, siendo los dedos y las muñecas las áreas más afectadas, superando el 50\% de los casos. \cite{arroyo-berezowsky_epidemiology_2021}

Estas lesiones requieren de tratamientos especializados evitando complicaciones y discapacidades permanentes, recurriendo así a fisioterapeutas, terapeutas ocupacionales o médicos especializados en rehabilitación y fisioterapia.  
\cite{arroyo-berezowsky_epidemiology_2021}

\subsubsection{Síndrome del túnel carpiano.}

El síndrome del túnel carpiano afecta al nervio mediano de la muñeca, responsable de la sensibilidad y movimiento de partes de la mano. La afectación se produce por la compresión del nervio mediano dentro del túnel carpiano, produciendo entumecimiento, dolor, hormigueo, debilidad, o daño muscular en la mano y dedos. \cite{sindrome_tunel}

En la \textit{Figura} \ref{fig:Tunel_carpiano} se puede observar la localización del túnel carpiano y donde ocurre la compresión del nervio mediano que provoca la aparición de este síndrome. \cite{sindrome_tunel}
\begin{figure}
    \centering
    
    \caption{Túnel carpiano. Fuente medlineplus.gov}
    \label{fig:Tunel_carpiano}
\end{figure}
\subsubsection{Síndrome de dolor regional complejo.}
El síndrome del dolor regional complejo es un síndrome amplio que cubre los casos de inflamación y dolor crónico. Puede ocurrir en cualquier parte del cuerpo, pero generalmente afectan brazos, piernas, manos o pies.  \cite{sindrome_regional_comple}

No está asociado a un daño de una estructura en específico, pero suelen ocurrir tras una lesión o evento médico, como una cirugía, un traumatismo, un accidente cerebrovascular o un ataque cardíaco. \cite{sindrome_regional_comple}

Los pacientes con este síndrome pueden experimentar algunos de estos síntomas: rigidez en las articulaciones afectadas, deterioro de la fuerza muscular y trastornos del movimiento, dolor repentino o no provocado que puede ser constante o cambiar con la actividad, dolor excesivo o duradero después del uso o contacto, adelgazamiento de un hueso o crecimiento óseo excesivo, sudoración y crecimiento de uñas y cabello de la articulación afectada, cambios en la textura de la piel o cambios en la temperatura y el color de la piel o hinchazón en la extremidad afectada. \cite{sindrome_regional_comple}

\subsubsection{Rizartrosis.}
La rizartrosis es un tipo de artrosis que afecta únicamente al pulgar, es muy común a medida que se envejece. Se produce por el deterioro del cartílago de la articulación carpometacarpiana.

Entre los síntomas más comunes se encuentran el dolor intenso, inflamación y disminución de la fuerza y del rango de movimiento.\cite{artritis_pulgar}

En la \textit{Figura} \ref{fig: Rizartrosis}, se puede observar el lugar de afectación de una forma más clara.

\begin{figure}
    \centering
    
    \caption{Rizartrosis. Fuente mayoclinic.org}
    \label{fig: Rizartrosis}
\end{figure}
\subsubsection{Tendinitis.}
La tendinitis es la inflamación o descomposición de los tendones.\cite{tendinitis-1}

Suele afectar hombro, pie, muñeca, rodilla, tobillo o cuello, y se caracteriza por el dolor intenso (empeora con movimiento) o sensibilidad en la zona afectada. \cite{tendinitis}

Las causas son muy amplias, pero suele ocurrir tras una lesión o sobrecarga.\cite{tendinitis-1}
\subsubsection{Fracturas.}

Las fracturas implican la rotura de huesos, causados generalmente por lesiones. Producen dolor, hinchazón y/o deformidades.

Para su curación es necesario la inmovilización u operación de la rotura, lo que lleva a una pérdida de fuerza en el área afectada y en algunos casos en el desarrollo del síndrome de dolor regional complejo.\cite{fracturas}
\subsubsection{Contractura de dupuytren.}

La contractura de dupytrent se produce por la formación de nudos de tejido debajo de la piel de la mano, estos nudos acaban formando un cordón grueso que jalan los dedos hacia la palma, quedando flexionados.  \cite{contractura_Dupuytren-1}

No existen causas firmes, pero está demostrado que suele heredarse. 

Esta afectación es dolorosa e incapacita el uso de la mano, requiere de terapia y/o operaciones para revertir o frenar la flexión. \cite{contractura_Dupuytren-1}

En la \textit{Figura} \ref{fig:Dupuytrent}, se puede observar cómo avanza la contractura.

\begin{figure}
    \centering
    
    \caption{Contractura de Dupuytrent. Fuente doctormartinezgutierrez.com}
    \label{fig:Dupuytrent}
\end{figure}

\subsubsection{Enfermedades reumáticas.}
Las enfermedades reumáticas incluyen más de 200 enfermedades, tienen en común que se manifiestan en el aparato locomotor, o bien como un mecanismo basado en la respuesta inmune o inflamatoria excesiva. Ambas manifestaciones son acompañadas de dolor y discapacidad. 
\cite{enfermedades_Reumáticas}
\begin{itemize}
    \item Artrosis(osteoartritis): enfermedad que solo afecta a las articulaciones, generalmente en manos, rodillas, caderas, el cuello y la parte inferior de la espalda. Se rompe el cartílago y se vuelve áspero. Causa dolor, rigidez, inflamación y menor movimiento en las articulaciones. En las manos suele producir nódulos de Heberden o nódulos de Bouchard (\textit{Figura} \ref{fig:Nódulos}), que producen la malformación de las manos. \cite{osteoartritis}
\cite{nodulos}
    \begin{figure}
        \centering
        
        \caption{Nódulos de Herbenden y Bouchard. Fuente cigna.com}
        \label{fig:Nódulos}
    \end{figure}
    \item Artritis: enfermedad autoinmune (sistema inmune ataca al tejido articular) que causa dolor, inflamación y rigidez en las articulaciones, en ocasiones se producen nódulos alrededor de ellas. 
    Muy común en muñeca y dedos. \cite{artritis}
\end{itemize}

\subsubsection{Enfermedades neurológicas.}
La enfermedades neurológicas engloban un conjunto de enfermedades que afectan en una o más partes del sistema nervioso (cerebro, médula espinal o neuronas), existen más de 600. 

Sus causas son diversas e incluyen factores como genes defectuosos, problemas con el desarrollo del sistema nervioso, enfermedades degenerativas, enfermedades de los vasos sanguíneos, lesiones, trastornos convulsivos, cáncer o infecciones. \cite{enfermedades_neurológicas}

La relación directa de los músculos con el sistema nervioso da como resultado que muchas de estas afectaciones se expresan en el movimiento, fuerza y/o agilidad del movimiento. 

Algunas enfermedades o patologías que afectan a la movilidad, fuerza y/o agilidad de los miembros superiores: 
\begin{itemize}
    \item Accidente cerebrovascular
    \item Esclerosis múltiple
    \item Esclerosis lateral amiotrófica
    \item Lesiones en la médula
    \item Síndrome de Guillain-Barré
\end{itemize}

\section{Implicaciones terapéuticas.}
Las implicaciones terapéuticas son los efectos y consecuencias que implican un tratamiento o dispositivo sobre un paciente. El uso del dispositivo puede ser interdisciplinar, ya sea durante sesiones de terapia ocupacional o fisioterapia o, incluso durante las consultas médicas de revisión, e implica la monitorización continua de los pacientes. Este dispositivo puede utilizarse en diversos momentos de las sesiones, ya sea solo con los sensores o bien con la adaptación de mangos u otros soportes adaptados.

El proceso es bastante sencillo, el profesional sanitario debe registrar a los pacientes que desea monitorizar e ir anotando en cada sesión la fuerza que son capaces de realizar los pacientes. Esto permitirá a los profesionales observar si existe una evolución favorable, negativa o estancada y, en consecuencia, decidir si las sesiones debiesen continuar o cesar. 

Otro uso relevante es la detección de la fatiga muscular durante las sesiones. Lo que permitiría realizar los cambios oportunos para la optimización total de las sesiones, o bien reducir el tiempo de estas. La fatiga muscular se detectaría si al realizar mediciones en varias ocasiones durante las sesiones, se registran picos de fuerza significativamente más bajos en comparación con las anteriores.

\section{Contexto de uso real.}
El dispositivo está diseñado para un perfil de pacientes amplio, en edad, patología o afectación. Puede utilizarse desde adolescentes hasta personas mayores. Aunque no se ha probado en niños, no se recomienda su uso, debido a que los sensores tienen un diámetro de 3 cm, lo que dificulta al menor la correcta disposición de sus dedos, debido al tamaño de sus manos. Para utilizarse en niños, se han de modificar el diámetro de los sensores o diseñar una adaptación para optimizar las mediciones

La integración del dispositivo durante una sesión de terapia ocupacional o fisioterapia es bastante amplia.

En el área de terapia ocupacional, podría adaptarse en la Tabla Canadiense que se utiliza como parte de las sesiones de toda patología que implique una afectación en mano. Para ello, se podrían colocar los sensores un adaptador, como el que he creado, compatible con la tabla canadiense. 

A continuación, el profesional debe realizar los siguientes pasos: 
\begin{enumerate}
    \item Abrir la interfaz, iniciar sesión y seleccionar o registrar al paciente.
    \item Seleccionar empezar a medir y expresar al paciente que debe ejercer fuerza durante el tiempo que la luz led esté encendida.
    \item Visualización del nuevo registro y si se desea visualización de la gráfica. 
\end{enumerate}

En el área de fisioterapia, se podría realizar en cualquier parte de la sesión, ya sea solo o con algún soporte que se diseñe. Los pasos a realizar serían iguales que en los de una sesión de terapia ocupacional. 
\begin{enumerate}
    \item Abrir la interfaz, iniciar sesión y seleccionar o registrar al paciente.
    \item Seleccionar empezar a medir y expresar al paciente que debe ejercer fuerza durante el tiempo que la luz led esté encendida.
    \item Visualización del nuevo registro y si se desea visualización de la gráfica. 
\end{enumerate}

Además, se podría utilizar durante las revisiones médicas, durante el reconocimiento. Pudiendo el médico visualizar si de una revisión a otra existen cambios. 

\section{ Comparativa con estudios o protocolos clínicos existentes.}

A partir de los estudios revisados en la sección 'Estado del arte' del apartado 'Conceptos teóricos', se va a comparar los estudios, prototipos o protocolos existentes, destacando ventajas, limitaciones y diferencias.

En los diseños analizados por los autores Juliana Gómez et al y Luis Carlos Ralon Gordillo, existe el objetivo común de la monitorización de la fuerza ejercida por pacientes en terapia de mano. 

Aunque en los dos se utiliza el sensor de fuerza resistivos (FSR) como elemento principal, podemos observar diferencias claras entre los estudios. En la tabla \ref{tab:comparativa_prototipos} se presenta una tabla comparativa de los dispositivos.
\begin{table}[h]
    \begin{tabular}{|p{3.5cm}|p{5cm}|p{6cm}|}
    \hline
    \rowcolor[HTML]{BFBFBF} 
    \textbf{Aspecto} & \textbf{Juliana Gómez et al.} & \textbf{Luis Carlos Ralón Gordill} \\ \hline
    Sensor utilizado & FSR & FSR  \\ \hline
    Número de sensores & 5 & 1 \\ \hline
    Uso del resorte & Transmisión de fuerza & Generar resistencia \\ \hline
    Mecanismo de transmisión & Mediante resorte & Mediante resorte\\ \hline
    Ventajas & Alta precisión & Uso en niños \\ \hline
    Limitaciones & Solo permite el agarre de precisión & Fallos en Resorte-Sensor  \\ \hline
    Coste  & No menciona & No menciona precio exacto, pero deja claro que busca producir el menos coste y al utilizar un único sensor el coste total es bajo.  \\ \hline
    \end{tabular}
    \caption{Comparativa de prototipos}
    \label{tab:comparativa_prototipos}
\end{table}

\section{Limitaciones y riesgos clínicos.}
Este dispositivo presenta un perfil de seguridad óptimo para su uso clínico, no supone ningún riesgo para pacientes o profesionales sanitarios. 

Los sensores que incorpora, son sensores resistentes al agua, que permite una desinfección rápida, óptima y efectiva entre pacientes mediante el uso de toallitas o paños húmedos con desinfectante. Siempre evitando que se sumerjan completamente en cualquier solución líquida, debido a que son componentes eléctricos.

Si se añaden accesorios:
\begin{itemize}
    \item Mango impresión 3D: su desinfección depende mucho del material con el que se ha impreso. Si utilizamos PLA (material pensado debido a su bajo coste), no debemos utilizar desinfectantes que contengan acetonas ya que este producto es capaz de degradarlo. Se podrían usar toallitas antibacterianas o paños humedecidos en soluciones desinfectantes.
    \item Otros soportes: se deben desinfectar según las especificaciones del material del que estén fabricados para no degradarlo.  
\end{itemize}

Un protocolo de limpieza adecuado garantiza las condiciones higiénicas necesarias para un uso seguro y continuado sin comprometer la salud de los pacientes o de los sanitarios que lo manipulen.

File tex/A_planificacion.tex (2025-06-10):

\apendice{Plan de Proyecto Software}
\section{Introducción}
Este documento tiene como objetivo una presentación de manera integral de todos los aspectos clave relacionados con el desarrollo y la implementación del proyecto. 

Para realizar un correcto desarrollo del proyecto, se ha definido una planificación temporal y se desarrollará una planificación económica para saber el coste aproximado total del producto desarrollado.
\section{Planificación temporal}
El proyecto se ha desarrollado a lo largo de un total de 14 semanas (aproximadamente 4 meses), durante las cuales se ha distribuido el trabajo de forma progresiva. 

En la \textit{tabla \ref{fig:Planificación}} se puede observar un resumen de la planificación temporal.
\begin{figure}[h]
        \centering
        
        \caption{Planificación del proyecto. Fuente propia}
        \label{fig:Planificación}
    \end{figure}

\section{Planificación económica}

La planificación económica consiste en el análisis total del precio del proyecto, incluyendo de manera individual los precios de los componentes del dispositivo (hardware), software y personal.

En la tabla \ref{tab:Costes Totales}, se puede observar el precio total del proyecto. Todos los precios han sido obtenidos en 2025, por lo cual el coste puede variar en un futuro. 

\subsection{Precios Hardware}
Para calcular el precio total de los costes de los materiales del dispositivo, se tiene en cuenta la suma total de los precios de los componentes, así como una suma de los gastos de producción y un porcentaje destinado a los beneficios. 

En la tabla \ref{tab:costes_hardware} se ha realizado un resumen de gastos y precio total. 
\begin{table}[]
\centering
\begin{tabular}{|l|p{8cm}|l|}
\hline
\rowcolor[HTML]{BFBFBF} 
\textbf{} & \textbf{Cálculos} & \textbf{Precio} \\ \hline
Gastos de los componentes & Suma total de los precios de los componentes del dispositivo & 61.7€\\ \hline
Gastos de producción & 10\% del precio de los
 componentes & 6.17€\\ \hline
Ingresos destinados a beneficio & 15\% de los gastos totales & 10.18€\\ \hline
\textbf{Total}& Suma total de los gastos & 78.05€ \\ \hline
\end{tabular}
\caption{Costes de dispositivos hardware.}
\label{tab:costes_hardware}
\end{table}

\subsubsection{\textbf{Desglose de precios de los componentes}}
Los precios de cada componente han sido seleccionados, siendo los mínimos encontrados en el mercado de páginas oficiales.
\begin{itemize}
    \item Placa Elegoo+USB: 15.99€
    \item Resistencias: 7*0.01299€= 0.091€
    \item Sensores de fuerza: 5*8.1€= 40.5€
    \item Elementos conectores (cables dupont): 29*0.07€=2.03€
    \item Protoboard: 2.83€
    \item Luz y botón: 0.20€
\end{itemize}
No se han contemplado los gastos de la compra de un ordenador, ya que en la actualidad en toda área del hospital se cuenta con uno de forma habitual. 

\subsubsection{Mango}

Para complementar con el desarrollo del proyecto, se ha diseñado un mango (véase \textit{Figuras} \ref{fig:Visión 1 del Mango.} \ref{fig:Visión 2 del Mango} \ref{fig:Visión 3 del Mango}) donde colocar los sensores. Diseñado especialmente para ser utilizado con la tabla canadiense. 

Está diseñado con la aplicación FreeCAD. Sus dimensiones son 60x60x135 mm. Cuenta con un agujero interior para insertar una de las barras de la tabla canadiense. 
Además, tiene cinco hendiduras destinadas a situar cada uno de los sensores.

\begin{figure}
    \centering
    
    \caption{Visión 1 del Mango. Fuente propia}
    \label{fig:Visión 1 del Mango.}
\end{figure}
\begin{figure}
    \centering
    
    \caption{Visión 2 del Mango. Fuente propia}
    \label{fig:Visión 2 del Mango}
\end{figure}
\begin{figure}
    \centering
    
    \caption{Visión 3 del Mango. Fuente propia}
    \label{fig:Visión 3 del Mango}
\end{figure}

Para tener este producto en físico, se ha pensado en la impresión 3D. Los costes de dicho accesorio difieren según donde y como se realice la impresión. 
Se ha considerado dos presupuestos diferentes según el método de impresión:
\begin{enumerate}
    \item Impresión propia: he seleccionado la impresora Ender-3 V3 SE \cite{Ender-3}, con un precio de 169 € y un filamento PLA\cite{PLA}, con un precio de 20.99 € el Kg. 
    \item Impresion mediante una empresa externa: he seleccionado la empresa ErreBiLAB \cite{ErreBiLAB}, ya que ofrece el precio más bajo de los que he visto disponibles. El precio de una pieza es de 41.03 €, este precio se va disminuyendo según el volumen de encargos. 
\end{enumerate}

La tabla \ref{tab:Impresión} resume lo que supondría esta adicción al prototipo (por cada mango), teniendo en cuenta la fabricación de 10 mangos. 
Ambas impresiones tienen los mismos requisitos.
\begin{table}[h] 
    \centering
    \begin{tabular}{|l|l|}
    \hline
    \rowcolor[HTML]{BFBFBF} 
    \textbf{Impresión propia} & \textbf{Imprimir mediante un 3º} \\ \hline
     17.6€ & 37€  \\ \hline
    \end{tabular}
    \caption{Costes de impresión}
    \label{tab:Impresión}
\end{table}

\subsection{Precios software}
No se incluye ningún gasto en software ya que todo el material utilizado es gratuito y de código abierto.

\subsection{Precio de personal}
Para calcular el salario del personal se ha partido de los datos publicados de salarios de ingenieros biomédicos, profesionales con un perfil técnico y formativo parecido al de un ingeniero de la salud.
Actualmente, en España el sueldo medio de un ingeniero biomédico es de 3.500€ \cite{SueldoBioing}\footnote{Página web de indeed, donde se puede ver sueldos de diferentes trabajos \cite{SueldoBioing}.}\cite{SUELDO}. Este sueldo es más bajo en recién egresados suponiendo un sueldo aproximado entre 1.500€ y 1.900€ mensuales \cite{Sueldo_egresado}\footnote{Página web de la UAX con información económica sobre el salario de un graduado en ingeniería biomédica \cite{Sueldo_egresado}.}.

En la tabla \ref{tab:costes_personal} se recoge el sueldo aproximado que debería cobrar por el proyecto un ingeniero de la salud.

\begin{table}[h]
\centering
\begin{tabular}{|l|l|}
\hline
\rowcolor[HTML]{BFBFBF} 
\textbf{} & \textbf{Precio} \\ \hline
Sueldo mensual & 1.600€ \\ \hline
\textbf{Total en 4 meses }& 6.400€ \\ \hline
\end{tabular}
\caption{Costes de sueldos del personal brutos.}
\label{tab:costes_personal}
\end{table}

\begin{table}[h]
\centering
\begin{tabular}{|l|l|}
\hline
\rowcolor[HTML]{BFBFBF} 
\textbf{} & \textbf{Precio} \\ \hline
Material & 78.05€ \\ \hline
Sueldo  &  6.400€ \\ \hline
\textbf{Total }& 6.478,05€ \\ \hline
\end{tabular}
\caption{Precio total del proyecto}
\label{tab:Costes Totales}
\end{table}

\section{Viabilidad legal}
Se debe tener en cuenta la normativa legal desde la creación de la idea hasta la comercialización y uso postventa.

Es esencial la implementación de leyes que garanticen el cumplimiento de la normativa aplicable que respalde los derechos y obligaciones del autor. Incluyendo desde leyes de las regulaciones técnicas, de propiedad intelectual y de responsabilidad profesional, conforme a lo establecido en la legislación.

Asimismo, se deben implementar medidas vigorosas que protejan la integridad de los usuarios y la confidencialidad de sus datos. 

Podemos dividir el proceso en 2 fases, la primera fase incluiría la creación de la idea, diseño, desarrollo y realización de pruebas, y una segunda fase que incluya la comercialización y postventa.

\subsection{1º Fase}

Durante la primera fase de creación de la idea, diseño, desarrollo y realización de las pruebas, se deberán tener en cuenta las siguientes normas legislativas: 

\begin{itemize}
    \item Ley 24/2015, de 24 de julio \cite{boe--2015-8328}, de Patentes: Establece los derechos, requisitos y procedimientos para obtener una patente y reforzar la seguridad jurídica. Esta última versión simplifica y agiliza el procedimiento.
    \item Real Decreto Legislativo 1/1996, de 12 de abril \cite{boe--1996-8930}, sobre la Ley de la Propiedad Intelectual: Establece los derechos de una obra al autor solo por el hecho de crearlo. 
    \item Real Decreto 192/2023, de 21 de marzo \cite{ministerio_de_sanidad_real_2023}, por el que se regulan los productos sanitarios. 
    \item UNE-EN 60601-1:2008 \cite{UNE2008}, norma que regula los requisitos generales para la seguridad básica y funcionamiento esencial de equipos electromédicos.
    \item UNE-EN ISO 14971:2020 \cite{UNE2020}, norma para la gestión de riesgos de dispositivos médicos.
\end{itemize}

\subsection{2º Fase}
La segunda fase de comercialización y postventa se deberá desarrollar según las siguientes normas legislativas: 
\begin{itemize}
    \item Ley 3/1991, de 10 de enero \cite{boe--1991-628}, de Competencia Desleal, sobre la promoción y comercialización del producto, realizando una publicidad lícita, veraz y no engañosa.
    \item Ley Orgánica 3/2018, de 5 de diciembre \cite{boe--2018-16673}, de Protección de Datos Personales y garantía de los derechos digitales.
    \item Reglamento (UE) 2016/679 del Parlamento Europeo y del Consejo, de 27 de abril de 2016 \cite{boees}, relativo a la protección de las personas físicas en lo que respecta al tratamiento de datos personales y a la libre circulación de estos datos.
    \item Ley 29/2006, de 26 de julio \cite{boe--2006-13554}, de garantías y uso racional de los medicamentos y productos sanitarios.
\end{itemize}

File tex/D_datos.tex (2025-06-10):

\apendice{Descripción de adquisición y tratamiento de datos}
\section{Descripción formal de los datos}

Como se ha especificado en la memoria, en el proyecto no se utilizan datos de fuentes externas, todos los datos son de elaboración propia.

Se pueden encontrar dos tipos de datos:
\begin{itemize}
    \item Proporcionados por el Usuario:
    \begin{itemize}
        \item Nombre del profesional. 
        \item Apellidos del profesional.
        \item Contraseña para acceder al área.
        \item Nombre del paciente.
        \item Apellidos del paciente.
    \end{itemize}
        \item Datos recolectados por el dispositivo.
        \begin{itemize}
            \item Fecha y hora de cada medición.
            \item Los valores de fuerza/presión que ejerce cada dedo durante la medición:
            \begin{itemize}
                \item Pulgar en Kg.
                \item Índice en Kg.
                \item Corazón en Kg.
                \item Anular en Kg.
                \item Meñique en Kg.
            \end{itemize}
        \end{itemize}
\end{itemize}

Los datos recogidos por el usuario tienen dos localizaciones finales. Aquellos relacionados con el profesional sanitario están recogidos en un archivo JSON, con una estructura interna tipo diccionario (clave: valor). Por otra parte, los datos de pacientes son almacenados en un archivo xlsx. Ambos archivos se encuentran cifrados para cumplir con la protección de datos.

Los datos recogidos por el sensor son números reales de hasta dos cifras decimales. Se almacenan en un archivo xlsx, donde se recogen los datos personales de los pacientes.
La unidad de medida es en Kilogramos (Kg), el rango de medida es desde 0 Kg hasta 4.5 Kg, con una frecuencia de parametrización de 0.5 Kg.

En la \textit{Figura} \ref{fig:Datosxlsx}, se puede observar el almacenamiento de los datos recogidos por el sensor. En cada hoja del xlsx se encuentran los datos recogidos, tanto de medición como nombre y apellidos de cada paciente. Además de los pesos, se recoge la fecha y hora de recogida de los datos. 
\begin{figure}
    \centering
    
    \caption{Ejemplo de recogida de datos. Fuente propia}
    \label{fig:Datosxlsx}
\end{figure}
\section{Descripción clínica de los datos.}

El conjunto de datos corresponde a la cuantificación de la fuerza ejercida, con el fin de una evaluación terapéutica. Los valores registrados se estiman mediante una parametrización y el uso de la interpolación lineal de los valores obtenidos por los sensores.

La escala de medidas utilizada, de 0 Kg a 4.5Kg, se basa en el estudio 'Dispositivo de medición de fuerza de los dedos y su rol en el seguimiento de las funciones de la mano'  \cite{GOMEZ2022}. Los investigadores estudian la fuerza ejercida por cada dedo de veinte sujetos con edades comprendidas entre veinte y cuarenta años.

En la tabla \ref{tab:medidas_dedos}, se puede observar los resultados medios en el estudio. 

\begin{table}[h]
    \begin{tabular}{|l|l|l|l|l|l|}
\hline
\rowcolor[HTML]{BFBFBF} 
    Mano & Pulgar (N) & Índice (N) & Medio (N) & Anular (N)& Meñique (N) \\ \hline 
    Izquierda & 32.88 & 29.64 & 29.42 & 29.32 & 25.86 \\ \hline
    Derecha & 34.43 & 31.48 & 31.42 & 30.96 & 27.08 \\ \hline
    \end{tabular}
    \caption{Medidas de los dedos de ambas manos}
    \label{tab:medidas_dedos}
\end{table}

La recolección de los datos, permiten a los profesionales identificar diferentes patrones de evolución de los pacientes de manera individual, ya sean mejoras, pérdidas o estabilidad sin progreso de fuerza. Facilitando así, la personalización de los tratamientos o el cese de estos.

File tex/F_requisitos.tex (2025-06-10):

\apendice{Especificación de Requisitos}
\section{Diagrama de casos de uso}
En la figura \ref{fig:Diagrama Casos de uso}, se puede observar el diagrama de casos de uso definido para el uso del dispositivo. 

Existen 3 personas diferentes, ingeniero, usuario (sanitario) y el paciente, con funciones diferentes.
\begin{figure}
    
    \caption{Diagrama Casos de uso. Fuente propia}
    \label{fig:Diagrama Casos de uso}
\end{figure}
\section{Explicación casos de uso.}

En esta sección se van a explicar de forma detallada cada uno de los casos de uso que se realizan, desde la puesta en marcha del dispositivo por los ingenieros hasta su uso en el hospital por los sanitarios.

\begin{table}[p]
	\centering
	\begin{tabularx}{\linewidth}{ p{0.21\columnwidth} p{0.71\columnwidth} }
		\toprule
		\textbf{CU-1}    & \textbf{Instalar Arduino IDE y Python}\\
		\toprule
		\textbf{Versión}        & 1.0    \\
		\textbf{Autor}  & Claudia Valentín Alguacil \\
		\textbf{Descripción}          & Instalación de ambas aplicaciones en el ordenador. \\
		\textbf{Precondición}         & Tener acceso al ordenador del profesional. \\
		\textbf{Acciones}             &
		\begin{enumerate}
			\def\labelenumi{\arabic{enumi}.}
			\tightlist
			\item Acceder a la web de ambas aplicaciones.
			\item Descargarlas en el ordenador.
                \item Instalarlas en el ordenador.
		\end{enumerate}\\
		\textbf{Postcondición}        &  Se podrán abrir ambas aplicaciones y ver el código. \\
		\textbf{Excepciones}          & Sin acceso a internet no se pueden descargar. \\
		\textbf{Importancia}          & Alta \\
		\bottomrule
	\end{tabularx}
	\caption{CU-1 Nombre del caso de uso.}
\end{table}

\begin{table}[p]
	\centering
	\begin{tabularx}{\linewidth}{ p{0.21\columnwidth} p{0.71\columnwidth} }
		\toprule
		\textbf{CU-2}    & \textbf{Cargar código en la placa Arduino }\\
		\toprule
		\textbf{Versión}              & 1.0    \\
		\textbf{Autor}                & Claudia Valentín Alguacil \\
		
		\textbf{Descripción}          & Cargar código que produce que los sensores midan la fuerza generada por el paciente.  \\
		\textbf{Precondición}         & Tener descargado e instalado Arduino IDE. \\
		\textbf{Acciones}             &
		\begin{enumerate}
			\def\labelenumi{\arabic{enumi}.}
			\tightlist
			\item Abrir código Arduino.ino en Arduino IDE.
			\item Conectar placa arduino al ordenador mediante el cable USB.
                \item Mandar el código desde la aplicación a la placa Arduino.
		\end{enumerate}\\
		\textbf{Postcondición}        &  Se puede medir pesos. \\
		\textbf{Excepciones}          & Conectar mal la placa o cable USB roto. \\
		\textbf{Importancia}          & Alta \\
		\bottomrule
	\end{tabularx}
	\caption{CU-2 Cargar código en la placa Arduino.}
\end{table}

\begin{table}[p]
	\centering
	\begin{tabularx}{\linewidth}{ p{0.21\columnwidth} p{0.71\columnwidth} }
		\toprule
		\textbf{CU-3}    & \textbf{Descargar códigos arduino e interfaz}\\
		\toprule
		\textbf{Versión}              & 1.0    \\
		\textbf{Autor}                & Claudia Valentín Alguacil \\
		
		\textbf{Descripción}          & Descargar los códigos que permiten utilizar el dispositivo y la interfaz. \\
		\textbf{Precondición}         & Tener acceso a los códigos. \\
		\textbf{Acciones}             &
		\begin{enumerate}
			\def\labelenumi{\arabic{enumi}.}
			\tightlist
			\item Acceder a la carpeta que contienen los archivos.
			\item Descargarlas en el ordenador.
		\end{enumerate}\\
		\textbf{Postcondición}        &  -- \\
		\textbf{Excepciones}          & Sin acceso a internet no se pueden descargar. \\
		\textbf{Importancia}          & Alta \\
		\bottomrule
	\end{tabularx}
	\caption{CU-3 Descargar los códigos que permiten utilizar el dispositivo y la interfaz}
\end{table}
% Caso de Uso 1 -> Consultar Experimentos.
\begin{table}[p]
	\centering
	\begin{tabularx}{\linewidth}{ p{0.21\columnwidth} p{0.71\columnwidth} }
		\toprule
		\textbf{CU-4} & \textbf{Instalar bibliotecas}\\
		\toprule
		\textbf{Versión}              & 1.0    \\
		\textbf{Autor}                & Claudia Valentín Alguacil \\
		
		\textbf{Descripción}          & Instalación de las bibliotecas necesarias para que el ordenador pueda procesar y abrir la interfaz sin problemas. \\
		\textbf{Precondición}         & Tener descargado python en el ordenador. \\
		\textbf{Acciones}             &
		\begin{enumerate}
			\def\labelenumi{\arabic{enumi}.}
			\tightlist
			\item Acceder al CMD del ordenador.
			\item Instalar una a una las bibliotecas.
		\end{enumerate}\\
		\textbf{Postcondición}        &  Se podrán abrir la interfaz sin ningún problema. \\
		\textbf{Excepciones}          & Si no se instalan correctamente, no se podrá abrir la interfaz. \\
		\textbf{Importancia}          & Alta \\
		\bottomrule
	\end{tabularx}
	\caption{CU-4 Instalar bibliotecas.}
\end{table}

\begin{table}[p]
	\centering
	\begin{tabularx}{\linewidth}{ p{0.21\columnwidth} p{0.71\columnwidth} }
		\toprule
		\textbf{CU-5}    & \textbf{Abrir interfaz}\\
		\toprule
		\textbf{Versión}              & 1.0    \\
		\textbf{Autor}                & Claudia Valentín Alguacil \\
		
		\textbf{Descripción}          & Proceso de abrir la interfaz por parte del sanitario. \\
		\textbf{Precondición}         & Que el ingeniero haya realizado correctamente sus funciones de descarga e instalación de los diferentes paquetes y aplicaciones requeridas. \\
		\textbf{Acciones}             &
        Opción 1: 
		\begin{enumerate}
			\def\labelenumi{\arabic{enumi}.}
			\tightlist
			\item Abrir el CMD del ordenador.
			\item Navegar hasta la carpeta en la que está el código descargado.
                \item Ejecutar el comando:
                
                \$ python app.py
		\end{enumerate}
        Opción dos:
        \begin{itemize}
        \def\labelenumi{\arabic{enumi}.}
		  \tightlist
            \item Abrir Visual Studio Code
            \item Abrir la carpeta donde se encuentra el código descargado.
            \item Ejecutar el comando:
                
            \$ python app.py
        \end{itemize} \\
		\textbf{Postcondición}        &  Se abre la interfaz. \\
		\textbf{Excepciones}          & Que haya algún fallo durante el proceso que realiza el ingeniero o que se acceda mal a la carpeta lo que produciría un error y no se desplegará la interfaz. \\
		\textbf{Importancia}          & Media. \\
		\bottomrule
	\end{tabularx}
	\caption{CU-6 Abrir interfaz.}
\end{table}

\begin{table}[p]
	\centering
	\begin{tabularx}{\linewidth}{ p{0.21\columnwidth} p{0.71\columnwidth} }
		\toprule
		\textbf{CU-7}    & \textbf{Registrarse}\\
		\toprule
		\textbf{Versión}              & 1.0    \\
		\textbf{Autor}                & Claudia Valentín Alguacil \\
		 
		\textbf{Descripción}          & El sanitario se crea una cuenta en la interfaz para que pueda acceder en otras ocasiones. Este proceso produce una recopilación de datos personales como son el nombre, apellidos, nombre de usuario y una contraseña. \\
		\textbf{Precondición}         & Que la interfaz abra correctamente y no tener un usuario ya registrado. \\
		\textbf{Acciones}             &
		\begin{enumerate}
			\def\labelenumi{\arabic{enumi}.}
			\tightlist
			\item Abrir interfaz.
			\item Seleccionar botón de 'Registrarse'.
                \item Rellenar todos los datos requeridos.
                \item Seleccionar botón de 'Registrarse'.
		\end{enumerate}\\
		\textbf{Postcondición}        &  Usuario registrado lo que permitiría acceder a la siguiente pantalla iniciando sesión. \\
		\textbf{Excepciones}          & Realizar mal el proceso de registro. \\
		\textbf{Importancia}          & Media \\
		\bottomrule
	\end{tabularx}
	\caption{CU-7 Nombre del caso de uso.}
\end{table}

\begin{table}[p]
	\centering
	\begin{tabularx}{\linewidth}{ p{0.21\columnwidth} p{0.71\columnwidth} }
		\toprule
		\textbf{CU-8}    & \textbf{Iniciar sesión}\\
		\toprule
		\textbf{Versión}              & 1.0    \\
		\textbf{Autor}                & Claudia Valentín Alguacil \\
		 
		\textbf{Descripción}          & El sanitario inicia sesión en la interfaz lo que permite que pueda visualizar los registros de sus pacientes, registrar nuevas cuantificaciones o pacientes. \\
		\textbf{Precondición}         & Tener una cuenta creada mediante el registro de nuevo usuario. \\
		\textbf{Acciones}             &
		\begin{enumerate}
			\def\labelenumi{\arabic{enumi}.}
			\tightlist
                \item Abrir interfaz.
			\item Seleccionar botón de 'Iniciar sesión'.
                \item Rellenar la información de inicio de  sesión (usuario y contraseña).
                \item Seleccionar botón de 'Iniciar sesión'.
			\item La interfaz verifica la información recibida.
                \item Se accede a otra pantalla donde se puede visualizar los registros de sus pacientes,registrar nuevas cuantificaciones o pacientes.
		\end{enumerate}\\
		\textbf{Postcondición}    &  Acceder a la siguiente pantalla de la interfaz.\\
		\textbf{Excepciones}  & Poner mal el usuario o contraseña. \\
		\textbf{Importancia} & Alta \\
		\bottomrule
	\end{tabularx}
	\caption{CU-8 Iniciar sesión .}
\end{table}

\begin{table}[p]
	\centering
	\begin{tabularx}{\linewidth}{ p{0.21\columnwidth} p{0.71\columnwidth} }
		\toprule
		\textbf{CU-9}    & \textbf{Registrar paciente.}\\
		\toprule
		\textbf{Versión}              & 1.0    \\
		\textbf{Autor}                & Claudia Valentín Alguacil \\
		 
		\textbf{Descripción}          & Registrar el paciente en la interfaz, supone una recolección de datos como su nombre y apellidos que se recogerán en una base de datos. \\
		\textbf{Precondición}  & Que no esté el paciente ya registrado y que el sanitario haya iniciado sesión.\\
		\textbf{Acciones}             &
		\begin{enumerate}
			\def\labelenumi{\arabic{enumi}.}
			\tightlist
                \item Seleccionar botón de 'Registrar paciente'.
                \item Rellenar la información de registro del paciente (nombre y apellidos).
                \item Seleccionar botón de 'Registrar paciente'.
		\end{enumerate}\\
		\textbf{Postcondición} &  Se podrán registrar datos del usuario. \\
		\textbf{Excepciones} & -- \\
		\textbf{Importancia}          & Alta \\
		\bottomrule
	\end{tabularx}
	\caption{CU-9 Registrar paciente.}
\end{table}

\begin{table}[p]
	\centering
	\begin{tabularx}{\linewidth}{ p{0.21\columnwidth} p{0.71\columnwidth} }
		\toprule
		\textbf{CU-10}    & \textbf{Conectar la placa de arduino al ordenador.}\\
		\toprule
		\textbf{Versión}              & 1.0    \\
		\textbf{Autor}                & Claudia Valentín Alguacil \\
		 
		\textbf{Descripción}          & Conectar el cable USB de la placa de arduino al puerto USB del ordenador. \\
		\textbf{Precondición} & Tener el dispositivo (placa de arduino y sensores).\\
		\textbf{Acciones}             &
		\begin{enumerate}
			\def\labelenumi{\arabic{enumi}.}
			\tightlist
			\item Conectar cable USB al puerto USB del ordenador.
		\end{enumerate}\\
		\textbf{Postcondición}        &  Se podrá realizar la cuantificación de la presión ejercida. \\
		\textbf{Excepciones}          & Conectar mal el USB. \\
		\textbf{Importancia}          & Alta. \\
		\bottomrule
	\end{tabularx}
	\caption{CU-10 Conectar la placa de arduino al ordenador.}
\end{table}

\begin{table}[p]
	\centering
	\begin{tabularx}{\linewidth}{ p{0.21\columnwidth} p{0.71\columnwidth} }
		\toprule
		\textbf{CU-11}    & \textbf{Iniciar medición}\\
		\toprule
		\textbf{Versión}              & 1.0    \\
		\textbf{Autor}                & Claudia Valentín Alguacil \\
		 
		\textbf{Descripción}          & Proceso de cuantificar los valores que recoge los sensores. \\
		\textbf{Precondición}         & Conectar placa de arduino al ordenador y tener desplegada la interfaz. \\
		\textbf{Acciones}             &
		\begin{enumerate}
			\def\labelenumi{\arabic{enumi}.}
			\tightlist
			\item Seleccionar al paciente con el que se quiera registrar una nueva cuantificación.
			\item Conectar la placa de arduino al ordenador.
                \item Seleccionar botón iniciar medición de la interfaz y pulsar el pin botón del dispositivo.
		\end{enumerate}\\
		\textbf{Postcondición}        &  Luz led se enciende.\\
		\textbf{Excepciones}          & No conectar la placa al ordenador. \\
		\textbf{Importancia}          & Media \\
		\bottomrule
	\end{tabularx}
	\caption{CU-11 Iniciar medición.}
\end{table}

\begin{table}[p]
	\centering
	\begin{tabularx}{\linewidth}{ p{0.21\columnwidth} p{0.71\columnwidth} }
		\toprule
		\textbf{CU-12}    & \textbf{Ejercer fuerza en los sensores}\\
		\toprule
		\textbf{Versión}              & 1.0    \\
		\textbf{Autor}                & Claudia Valentín Alguacil \\
		 
		\textbf{Descripción}          & El paciente debe de realizar fuerza en los sensores del dispositivo, colocando cada dedo según el sensor en el que corresponde. \\
		\textbf{Precondición}         &  Casos de Uso: 09, 11 y 12\\
		\textbf{Acciones}             &
		\begin{enumerate}
			\def\labelenumi{\arabic{enumi}.}
			\tightlist
			\item Conectar placa arduino al ordenador.
			\item Seleccionar iniciar medición.
                \item Hacer fuerza en la mano.
		\end{enumerate}\\
		\textbf{Postcondición}        &  Se podrá observar los datos recogidos en la tabla. \\
		\textbf{Excepciones}          & Mala captación de datos. \\
		\textbf{Importancia}          & Media. \\
		\bottomrule
	\end{tabularx}
	\caption{CU-12 Hacer fuerza en el dispositivo.}
\end{table}

\begin{table}[p]
	\centering
	\begin{tabularx}{\linewidth}{ p{0.21\columnwidth} p{0.71\columnwidth} }
		\toprule
		\textbf{CU-13}    & \textbf{Ver seguimiento pacientes}\\
		\toprule
		\textbf{Versión}              & 1.0    \\
		\textbf{Autor}                & Claudia Valentín Alguacil \\
		
		\textbf{Descripción}          & Visualización de los registros de los pacientes realizados mediante la cuantificación de la presión/fuerza que se ejerce a los sensores.\\
		\textbf{Precondición}         & Tener registros \\
		\textbf{Acciones}             &
		\begin{enumerate}
			\def\labelenumi{\arabic{enumi}.}
			\tightlist
			\item Acceder a la pantalla del paciente del que queramos observar el seguimiento.
			\item Seleccionar 'Visualización Registro'.
                \item Visualizar todos los registros realizados.
		\end{enumerate}\\
		\textbf{Postcondición}        &  -- \\
		\textbf{Excepciones}          & -- \\
		\textbf{Importancia}          & Baja/Media \\
		\bottomrule
	\end{tabularx}
	\caption{CU-13 Ver seguimiento pacientes.}
\end{table}

\newpage

\section{Prototipos de interfaz o interacción con el proyecto.}

Para este proyecto se ha diseñado un prototipo de interfaz para ordenador tipo desplegable, en base a las necesidades y requisitos para su uso. 

Esta interfaz creada consta de 8 pantallas:
\begin{enumerate}
    \item Pantalla Principal: es la pantalla de presentación (véase \textit{Figura} \ref{fig:Pantalla principal}), en ella se muestra el logo de la aplicación, dos botones, iniciar sesión y registrarse, y un recuadro con información relevante sobre la interfaz.
    \begin{figure}
        \centering
        
        \caption{Pantalla principal. Fuente Propia.}
        \label{fig:Pantalla principal}
    \end{figure}
    \item Pantalla Inicio Sesión: es la pantalla que permite al usuario (sanitario) iniciar sesión en la interfaz (véase \textit{Figura} \ref{fig:Pantalla Inicio Sesión}), en ella se debe introducir el usuario y contraseña personal de cada usuario para acceder al área. Desde esta pantalla, se puede volver a la pantalla principal seleccionando el botón 'Volver' o bien, acceder a la siguiente pantalla seleccionando el botón 'Entrar'.
\begin{figure}
    \centering
    
    \caption{Pantalla Inicio Sesión. Fuente Propia.}
    \label{fig:Pantalla Inicio Sesión}
\end{figure}
    \item Pantalla Registrar Usuario: es la pantalla que permite al usuario (sanitario) registrarse en la interfaz (véase \textit{Figura} \ref{fig:Pantalla Registrar Usuario}), en ella se debe introducir el nombre, apellidos, nombre de usuario y contraseña personal. Estos datos se almacenarán en un documento Json. Desde esta pantalla, se puede volver a la pantalla principal sin registrar un nuevo usuario seleccionando el botón 'Volver' o bien, registrar un nuevo usuario seleccionando el botón 'Registrarse'. Realizando la última acción la aplicación te dirige de forma automático a la pantalla principal.
    \begin{figure}
        \centering
        
        \caption{Pantalla Registrar Usuario. Fuente propia}
        \label{fig:Pantalla Registrar Usuario}
    \end{figure}
    \item Pantalla de Inicio: es la pantalla principal de cada usuario (véase \textit{Figura} \ref{fig:Pantalla Inicio}). Consta de un recuadro con el nombre y apellidos del profesional, un mensaje de bienvenida y dos botones, uno de seleccionar paciente y otro de registrar paciente. Si seleccionamos el primero de ellos, sale un menú desplegable con los diferentes nombres y apellidos de los pacientes registrados. Si seleccionamos el segundo botón, nos dirige a una pantalla nueva que nos permitirá el registro de un nuevo paciente.
    \begin{figure}
        \centering
        
        \caption{Pantalla Inicio. Fuente Propia}
        \label{fig:Pantalla Inicio}
    \end{figure}
    \item Pantalla Registrar paciente: es la pantalla que permite al usuario (sanitario) registrar a un nuevo paciente en la base de datos (véase \textit{Figura} \ref{fig:Pantalla registrar Paciente}), en ella se debe introducir el nombre y apellidos del paciente. Estos datos se almacenarán en un documento Excel, donde, además, se guardarán las diferentes cuantificaciones de fuerza. Desde esta pantalla, se puede volver a la pantalla principal sin registrar un nuevo paciente seleccionando el botón 'Volver' o bien, registrar un nuevo paciente seleccionando el botón 'Registrar paciente'. Realizando la última acción la aplicación te dirige de forma automática a la pantalla de inicio.
    \begin{figure}
        \centering
        
        \caption{Pantalla registrar Paciente. Fuente propia}
        \label{fig:Pantalla registrar Paciente}
    \end{figure}
    \item Pantalla paciente: es la pantalla general de cada paciente (véase \textit{Figura} \ref{fig:Pantalla paciente}). Esta contiene un recuadro superior con el nombre y apellidos del paciente y 4 botones, 'Iniciar medición', 'Visualización registro', 'Visualización gráfica' y 'Volver. Al pulsar sobre el primero de ellos realiza el proceso de medir la fuerza ejercida en los sensores, esta cuantificación se guarda automáticamente en una base de datos. Al pulsar sobre el segundo y tercer botón se abre una pantalla nueva, y al pulsar sobre el último botón vuelve a la pantalla de inicio.
    \begin{figure}
        \centering
        
        \caption{Pantalla paciente. Fuente propia}
        \label{fig:Pantalla paciente}
    \end{figure}
    \item Pantalla visualización: es la pantalla a la que se accede al pulsar el botón 'Visualización registro' en la pantalla paciente. En ella se muestra el registro de las mediciones realizadas por el paciente (véase \textit{Figura} \ref{fig:Pantalla visualización}). Tiene un botón 'Volver' para poder volver a la pantalla paciente y hacer nuevas mediciones, ver los registros en formato gráfica o seguir volviendo atrás y elegir un paciente nuevo.
    \begin{figure}
        \centering
        
        \caption{Pantalla visualización registros. Fuente propia}
        \label{fig:Pantalla visualización}
    \end{figure}
    \item Pantalla visualización gráfica: es la pantalla a la que se accede al pulsar el botón 'Visualización gráfica' en la pantalla paciente. En ella se muestra el registro de las mediciones realizadas por el paciente en forma de una gráfica de líneas. (véase \textit{Figura} \ref{fig:Pantalla grafica}). Tiene un botón 'Volver' para poder volver a la pantalla paciente y hacer nuevas mediciones, ver los registros en formato tabla o seguir volviendo atrás y elegir un paciente nuevo.
    \begin{figure}
        \centering
        
        \caption{Pantalla visualización registros formato gráfica. Fuente propia}
        \label{fig:Pantalla grafica}
    \end{figure}
\end{enumerate}

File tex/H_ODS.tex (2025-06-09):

\apendice{Anexo de sostenibilización curricular}

El desarrollo sostenible es un conjunto de principios aprobados en 2015 por la Organización de las Naciones Unidas (ONU), y recogidos en la Agenda 2030. La Agenda 20230 para el Desarrollo Sostenible es un plan de acción a nivel global, actualmente respaldada por los 193 países que pertenecen a la ONU, a favor de las personas, el planeta y las prosperidad económica, sanitaria y social, que además aboga por la paz universal y el acceso a la justicia \cite{Agenda2030_gobierno}.

El desarrollo sostenible es considerado una oportunidad de mejora en la calidad de vida de todos los ciudadanos, sin excluir a nadie. Esto implica, entre otros objetivos, erradicar la pobreza, poner fin a todas las guerras, fomentar el acceso a una educación de calidad, adecuada y universal, garantizar unos servicios sanitarios universales, eficaces y de calidad, promover ciudades y comunidades inclusivas, seguras, resilientes y sostenibles. Para cumplir con todos los objetivos se requiere de la cooperación de instituciones y gobiernos que aseguren mediante leyes e impulsos el cumplimiento y colaboración por parte de la sociedad. \cite{ODS}

Cada uno de los 17 Objetivos de Desarrollo Sostenible (ODS), conlleva unas metas concretas cuyos fines deben alcanzarse antes del año 2030. En la \textit{Figura} \ref{fig:ODS}, se exponen cada uno de estos ODS.

\begin{figure}
    \centering
    
    \caption{17 ODS. Fuente un.org}
    \label{fig:ODS}
\end{figure}

Dentro del desarrollo de este proyecto, se han identificado tres ODS particularmente relacionados, ya que la creación de un dispositivo de medición de la fuerza de los dedos y seguimiento puede contribuir con los objetivos marcados en la Agenda 2030, no solo en términos tecnológicos, sino también sociales y sanitarios.

En primer lugar, el ODS 3: Salud y Bienestar, cobra especial relevancia. Este objetivo busca el acceso universal a servicios sanitarios, garantizar una vida sana y promover el máximo bienestar posible para todas las personas y en todos los rangos de edades, haciendo especial hincapié en aquellos grupos más vulnerables como mujeres y niños . El dispositivo y aplicación desarrollados en este proyecto tiene como finalidad facilitar el seguimiento y evaluación de los pacientes en rehabilitación de la mano, proporcionando una herramienta especialmente útil en contextos clínicos y terapéuticos. Asimismo, su diseño desde el inicio se ha planteado con un enfoque versátil, accesible y de bajo coste, lo cual permite su implementación en distintos tipos de centros sanitarios, incluyendo aquellos con recursos limitados. De este modo, se promueve una atención sanitaria más equitativa, eficiente y adaptada a las necesidades individuales de cada paciente. \cite{salud_ODS}

En segundo lugar, el ODS 9: Industria, Innovación e Infraestructura, cuyo objetivo es construir infraestructuras resilientes, promover la industrialización sostenible y fomentar la innovación, se ve relacionado de forma directa en el proyecto. La creación de un dispositivo médico funcional, accesible y basado en tecnologías, representa una aportación directa a la innovación tecnológica aplicada a la salud. \cite{infraestructura_ODS}

Para finalizar, el ODS 10: Reducción de las Desigualdades, también se ve reflejado en este proyecto. Este objetivo busca reducir la desigualdad en y entre los países, distribuyendo equitativamente los recursos, invirtiendo en la enseñanza y el desarrollo de capacidades, implementando medidas de protección social, luchar contra la discriminación, apoyando a los grupos marginados y fomentando la cooperación internacional para un comercio y sistemas financieros justos. Los prototipos desarrollados en el proyecto pueden contribuir a la ampliación en el acceso a tecnologías en medicina, permitiendo que personas con escasos recursos puedan beneficiarse de tratamientos más personalizados, medibles y eficaces. Además, la posibilidad de adaptabilidad del sistema permite su uso por parte un gran número de profesionales para usuarios con diferentes patologías, lo que lo hace especialmente útil. \cite{desigualdades_ODS}

En conclusión, la creación de estos prototipos supone una pequeña contribución al cumplimiento de los ODS. Proporcionando una nueva tecnología, que impulsa el crecimiento de la industria y ámbitos sanitarios, fomentando la inclusión y reduciendo desigualdades.

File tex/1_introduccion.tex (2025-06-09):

\capitulo{1}{Introducción}
Este proyecto surgió durante el desarrollo de las prácticas curriculares que realicé en diversas áreas del Hospital Universitario de Burgos, en particular en el área de Terapia Ocupacional. 

Durante este proceso pude observar la forma de trabajar de las terapeutas ocupacionales, los recursos que tienen y darme cuenta de las dificultades que enfrentan en su día a día, tanto por falta de recursos como por la falta de implementación tecnológica que les permitiría tanto optimizar los tratamientos como mejorar en el seguimiento de estos mismos.

Una de esas muchas necesidades que me comunicaron fue la de tener un dispositivo capaz de medir la fuerza ejercida por un paciente con la mano al realizar ejercicios. De tal manera que el dispositivo permitiría visualizar el valor de presión en el momento, sino también poder realizar un registro para que pudieran documentar estas mediciones para poder observar la evolución o no evolución de un paciente y/o ver el momento de la sesión en el que el paciente se fatiga.

El dispositivo no debe centrarse en una única patología de la mano, además tiene ser útil tanto para el tratamiento como para el seguimiento de las diferentes patologías de la mano.

La presente memoria del proyecto está estructurada en 8 capítulos, organizados especialmente para que faciliten su comprensión.
\begin{itemize}
    \item \textbf{Capítulo 1}: Descripción del contenido del proyecto, estructura de la memoria y materiales utilizados.
    \item \textbf{Capítulo 2}: Objetivos principales del proyecto y personales.
    \item \textbf{Capítulo 3}: Descripción de conceptos teóricos y estado del arte.
    \item \textbf{Capítulo 4}: Discusión clínica, exposición de la problemática y comparación con otros prototipos.
     \item \textbf{Capítulo 5}: Descripción de técnicas y herramientas utilizadas.
    \item \textbf{Capítulo 6}: Resumen de resultados.
    \item \textbf{Capítulo 7}: Conclusiones.
    \item \textbf{Capítulo 8}: Posibles líneas futuras que pueda tener el proyecto.
\end{itemize}
 
El conjunto de ficheros y desarrollo del proyecto están recopilados \href{https://github.com/cva1003/TFG}{aquí}. Para comprender mejor la estructura de los ficheros se recomienda revisar el Anexo C.

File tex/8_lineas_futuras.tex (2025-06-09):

\capitulo{8}{Líneas Futuras}
Al tratarse de un prototipo, se pueden realizar varias mejoras para llegar a un dispositivo comerciable, robusto y de bajo coste.

Una de las primeras mejoras que podría implementarse es la eliminación del botón físico del dispositivo destinado a inicio de la medición, de manera que esta se active directamente al presionar 'Iniciar medición' en la interfaz. 

Asimismo, se podrían diseñar diferentes tipos de mangos donde poner los sensores, variando tanto en tamaño como en los materiales a utilizar. Debido a que el medio utilizado es impresión 3D, las posibilidades de personalización son muy amplias. Se podría utilizar material semielástico, permitiendo así una leve deformación, ya que estos materiales combinan flexibilidad y resistencia. Otra posibilidad, podría ser emplear compuestos como mezclas de PLA con polvo metálico, que aportarían mayor rigidez y peso, lo que supondría un desafío adicional durante el ejercicio.

De otra manera, se puede emplear un cambio en el tamaño ajustando el diámetro del mango. Contar con estos diferentes diámetros facilita el agarre para las personas según las diferentes patologías que tengan ya sea que afecten la movilidad o fuerza de la mano.

Además, se podría implementar una funcionalidad que permita generar un informe final por paciente imprimible, permitiendo que forme parte de la historia clínica. Usando la biblioteca FPDF, podemos generar archivos pdf con posibilidad de imprimir.

Por último, mejorar el desplegable para que se abra como una aplicación más de escritorio y no haga falta acceder desde el CMD o terceras aplicaciones como Visual Studio Code.
Con KivyMD solo se podrá realizar esto para archivos con sistema operativo Windows, para realizarlo se deberá crear un paquete especial siguiendo los pasos de la documentación de Kivymd \cite{kivymdapp}, realizando los oportunos cambios en los archivos \href{https://github.com/cva1003/TFG/blob/main/Aplicaci%C3%B3nEscritorio/app.py}{app.py} e \href{https://github.com/cva1003/TFG/blob/main/Aplicaci%C3%B3nEscritorio/interfaz.kv}{interfaz.kv}.

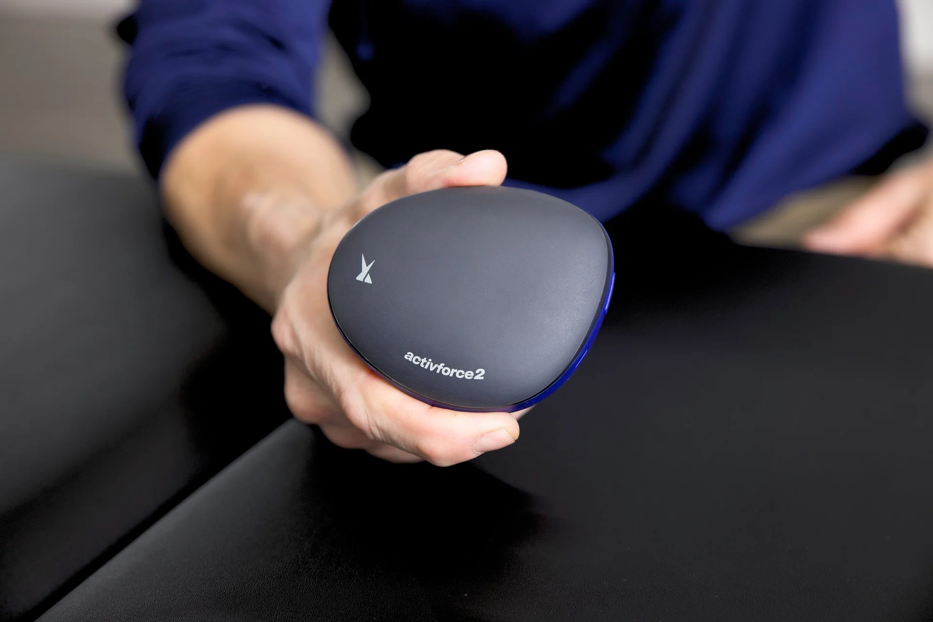
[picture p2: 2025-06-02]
img/ActivForce_Device.jpg

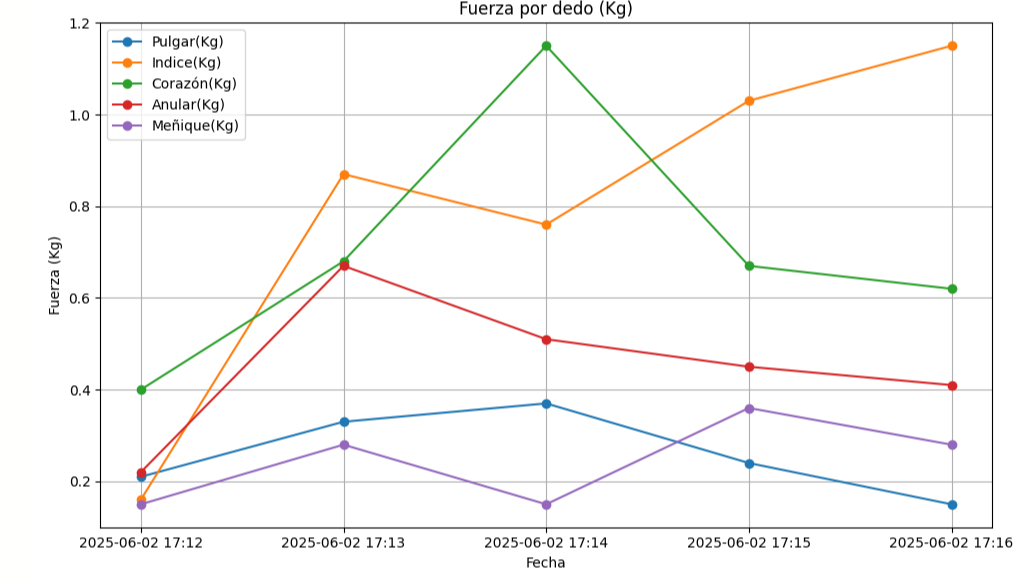
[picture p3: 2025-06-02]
img/grafica_fuerza.png

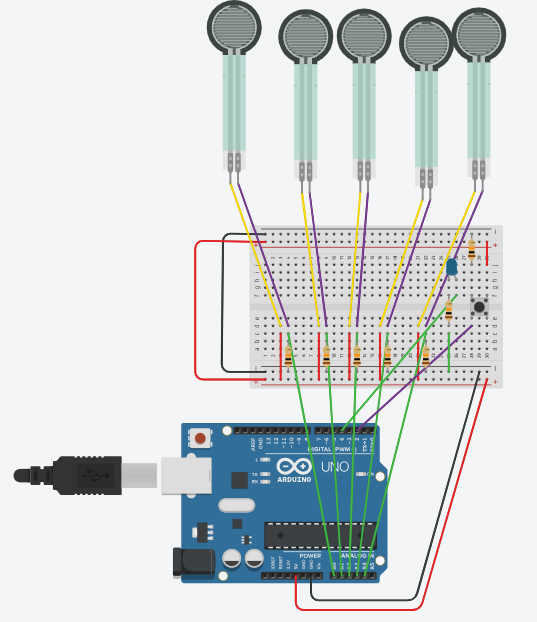
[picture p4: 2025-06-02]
img/Circuito.png

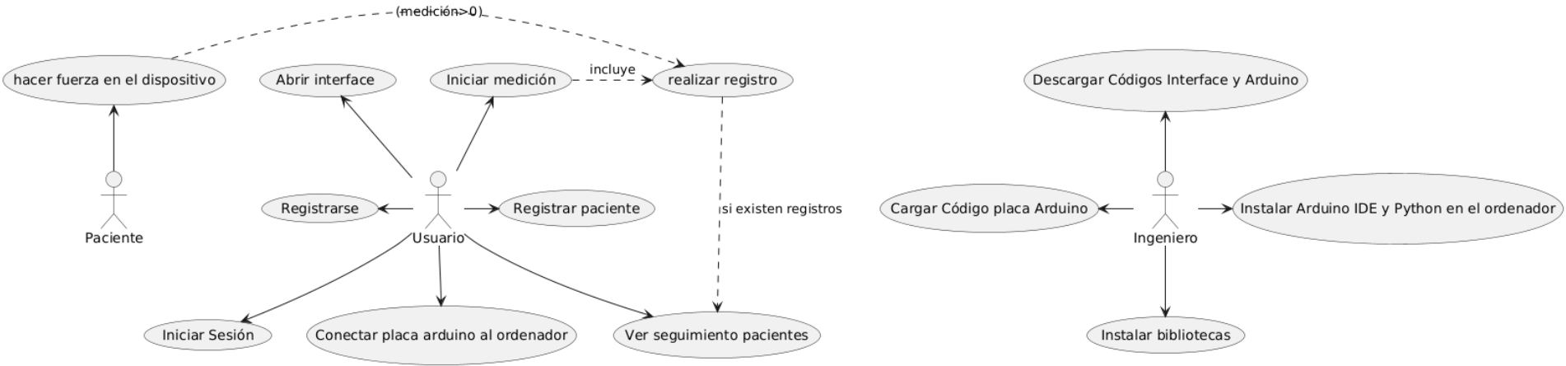
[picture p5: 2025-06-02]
img/Diagrama Casos de Uso.png

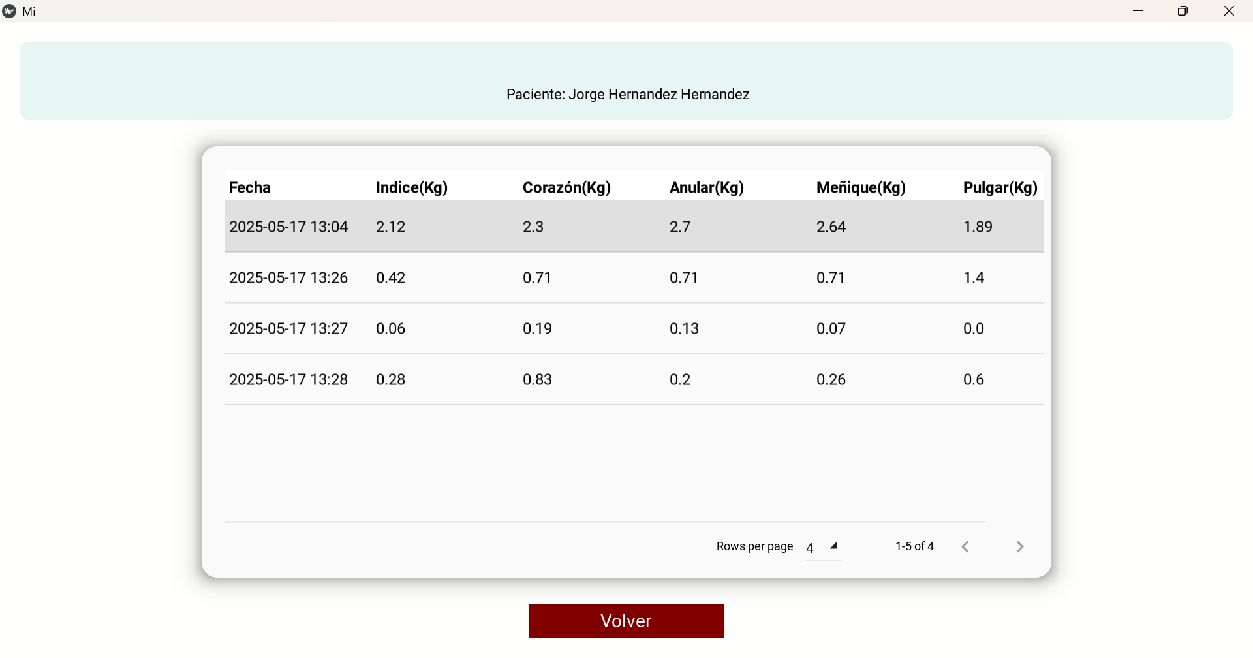
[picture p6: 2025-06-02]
img/Pantalla visualización.png

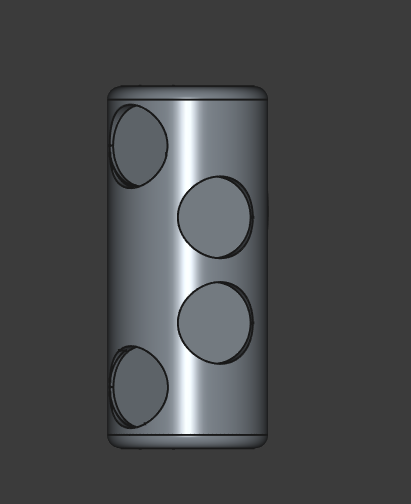
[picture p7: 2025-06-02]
img/Mango1.png

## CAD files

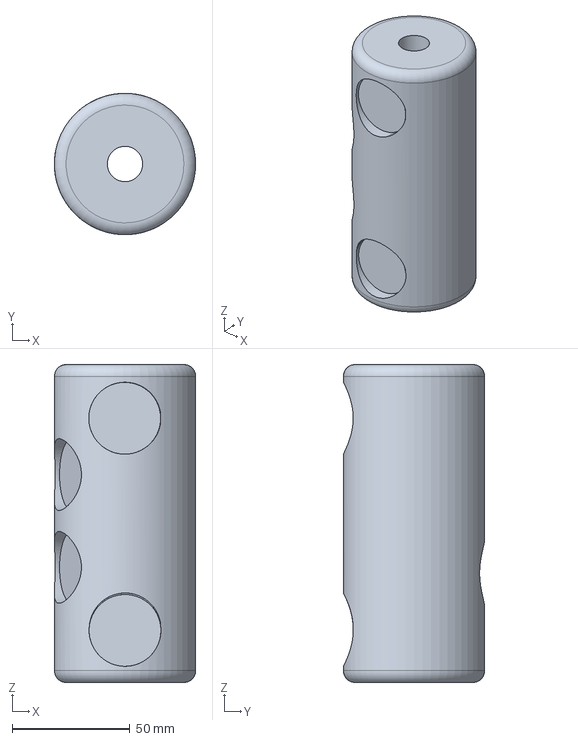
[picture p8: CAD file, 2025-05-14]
diseño/prototipo 2 mango (6cm diametro).FCStd
60.0 x 60.0 x 135.0 mm

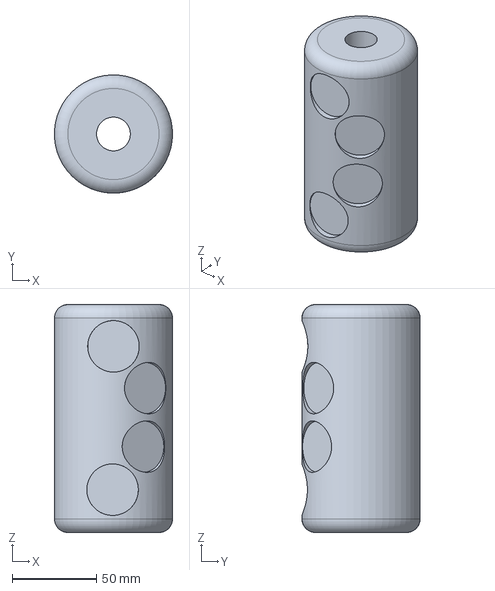
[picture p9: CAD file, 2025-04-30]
diseño/prototipo 1.FCStd
69.9 x 70.0 x 135.0 mm

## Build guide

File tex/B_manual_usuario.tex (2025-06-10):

\apendice{Documentación de usuario}
En esta sección del anexo se han definido aquellos requisitos necesarios para la ejecución y puesta en marcha del proyecto. 
\section{Requisitos software y hardware para ejecutar el proyecto.}
\subsection{Requisitos del software}
Para el correcto funcionamiento es necesario tener instalado en el ordenador todas las herramientas y programas que se han utilizado. 
\begin{itemize}
    \item Python: Este programa es esencial para que el código se ejecute y se abra el desplegable.
    \item Arduino IDE: Este programa es necesario para tener una comunicación y conexión correcta entre la placa de arduino y el ordenador.
    \item Editor de texto/código: No es estrictamente necesario la instalación de un editor de texto/código como Visual Studio Code, pero sí puede facilitar el uso tanto al usuario como a posibles profesionales ingenieros para la solución de errores.
    \item Instalación de bibliotecas:
    \begin{itemize}
        \item Pandas: manipulación y análisis de datos estructurados(tablas).
        \item Pyserial: comunicación con puerto serie.
        \item Kivy: paquete que permite la creación de la interfaz gráfica
        \item kivymd: paquete que permite la creación de la interfaz gráfica
        \item Openpyxl: abrir y modificar archivos Excel.
        \item Cryptography: encriptar y desencriptar documentos, crea una clave para generar un cifrado simétrico.
    \end{itemize}

\begin{table}[]
\centering
\begin{tabular}{|l|l|}
\hline
\rowcolor[HTML]{BFBFBF} 
\textbf{Software} & \textbf{Descripción} \\ \hline
Python & Versión 3.13\\ \hline
Arduino IDE & Versión 2.3.6\\ \hline
Bibliotecas & Versiones más actualizadas\\ \hline
\end{tabular}
\caption{Requisitos Software}
\label{tab:Requisitos_Software}
\end{table}
\end{itemize}
\subsection{Requisitos del hardware}
Para el correcto funcionamiento es necesario el uso del dispositivo creado, un ordenador y el cable USB que conecte el ordenador con la placa de Arduino.
\section{Instalación / Puesta en marcha}
\subsection{Python}

El proceso de descargar Python es sencillo. Desde la web oficial de Python \cite{Python}, en la pantalla inicial (ver \textit{Figura} \ref{fig:Python}), aparece un botón de descarga (señalado con una flecha roja). Al seleccionarlo, la descarga se inicia de forma automática. Una vez descargado el archivo, el proceso de instalación se realiza de una forma similar a la de otras aplicaciones: se decide la ruta de instalación deseada y el programa queda instalado en nuestro ordenador.

\begin{figure}[h]
        \centering
        
        \caption{Pantalla descargar Python. Fuente python.org}
        \label{fig:Python}
    \end{figure}
\subsection{Arduino IDE}
Proceso muy similar a la instalación de Python. Desde la web oficial de Arduino IDE \cite{Arduino}, en la pantalla inicial (ver \textit{Figura} \ref{fig:Arduino}), aparece una sección de diferentes opciones de descarga según el sistema operativo instalado en el ordenador. Al seleccionar el archivo correspondiente a nuestro sistema operativo, se abre una ventana nueva en la cual hay que clicar el botón 'Just Download' y la descarga se iniciará de forma automática. Una vez descargado el archivo, el proceso de instalación se realiza de una forma similar a la de otras aplicaciones: se decide la ruta de instalación deseada y el programa queda instalado en nuestro ordenador.
    \begin{figure}[h]
        \centering
        
        \caption{Pantalla descargar Arduino. Fuente arduino.cc}
        \label{fig:Arduino}
    \end{figure}
\subsection{Instalación de bibliotecas}
La instalación de las bibliotecas se hace desde la consola del sistema (CMD). Para abrirla, basta con buscar CMD en el buscador de Windows y hacer clic sobre el resultado.
Una vez abierta la consola (ver \textit{Figura} \ref{fig:CMD}), se deben introducir los siguientes comandos para la instalación de las bibliotecas:
\begin{itemize}
    \item pip install pandas
    \item pip install pyserial
    \item pip install kivy 
    \item pip install kivymd
    \item pip install openpyxl
    \item pip install cryptography
\end{itemize}

\begin{figure}[h]
    \centering
    
    \caption{Pantalla CMD. Fuente Propia}
    \label{fig:CMD}
\end{figure}

\subsection{Prototipo}
Para la puesta en marcha del prototipo físico, es necesario la correcta colocación de todos los componentes y mandar el código a la placa de forma correcta. 

En la \textit{Figura} \ref{fig:Vista esquemática prototipo}, se puede observar un esquema del prototipo físico.
\begin{figure}
    \centering
    
    \caption{Vista esquemática prototipo. Fuente propia}
    \label{fig:Vista esquemática prototipo}
\end{figure}
En las \textit{Figuras} \ref{fig:CodigoArduino1} \ref{fig:CodigoArduino2} \ref{fig:CodigoArduino3}, en orden se puede observar el código necesario para el correcto funcionamiento.
\begin{figure}
    \centering
    
    \caption{Código Arduino para el prototipo físico. Fuente propia}
    \label{fig:CodigoArduino1}
\end{figure}
\begin{figure}
    \centering
    
    \caption{Código Arduino para el prototipo físico. Fuente propia}
    \label{fig:CodigoArduino2}
\end{figure}
\begin{figure}
    
    \caption{Código Arduino para el prototipo físico. Fuente propia}
    \label{fig:CodigoArduino3}
\end{figure}
\section{Manuales y/o Demostraciones prácticas}  

El dispositivo desarrollado en este proyecto se puede utilizar de maneras diferentes según la aplicación que se le quiera dar. A continuación, se va a realizar una demostración práctica del dispositivo sin ningún tipo de accesorio complementario. 

En primer lugar, se debe abrir el prototipo de la interfaz desarrollada (véase \textit{Figura} \ref{fig:Pantalla principal}). Si ya se dispone de una cuenta, se debe iniciar sesión; en caso contrario, es obligatorio crear una cuenta nueva y a continuación acceder iniciando sesión.

 \begin{figure}
        \centering
        
        \caption{Pantalla principal. Fuente Propia.}
        \label{fig:Pantalla principal}
\end{figure}

Una vez dentro, existen dos opciones, seleccionar un paciente ya registrado o bien añadir uno nuevo. Elegido o registrado el paciente, el usuario podrá elegir entre registrar una nueva medición o consultar las mediciones previamente almacenadas.

En caso de seleccionar la opción de registrar una nueva medición, se debe conectar la placa Arduino al puerto USB del ordenador. Una vez conectada, es necesario colocar los sensores sobre una superficie dura y estable (véase \textit{Figura} \ref{fig:sensores_mesa}), asegurando así la precisión de la lectura, colocar los dedos sobre cada sensor teniendo en cuenta la colorimetría de los cables: rojo-pulgar, naranja-índice, amarillo-corazón, verde-anular, marrón-meñique (véase \textit{Figura} \ref{fig:sensor_mano}). A continuación, se debe presionar el botón “Iniciar medición” en la interfaz y, seguidamente, pulsar el botón físico de la placa arduino, lo que dará inicio al proceso de medición. Durante este proceso, se encenderá una luz Led (véase \textit{Figura} \ref{fig:luz}) que indica que el dispositivo está recolectando los datos.
\begin{figure}
    \centering
    
    \caption{Sensores. Fuente propia}
    \label{fig:sensores_mesa}
\end{figure}
\begin{figure}
    \centering
    
    \caption{Disposición de los dedos en los sensores. Fuente propia}
    \label{fig:sensor_mano}
\end{figure}
\begin{figure}
    \centering
    
    \caption{Luz led se enciende al empezar a recoger datos. Fuente propia}
    \label{fig:luz}
\end{figure}

Cuando el Led se apague, la medición habrá finalizado. Los resultados se podrán visualizar en la interfaz, ya sea de forma gráfica o numérica, seleccionando los botones correspondientes de “Visualización gráfica” o “Visualización registro”.

En la \textit{Figura} \ref{fig:Grafico} y en la \textit{Figura} \ref{fig:registro} se puede observar un registro realizado ejerciendo diferentes presiones a los sensores. 
\begin{figure}
    \centering
    
    \caption{Gráfica de los datos recogidos. Fuente propia}
    \label{fig:Grafico}
\end{figure}

\begin{figure}
    \centering
    
    \caption{Tabla de los datos recogidos. Fuente propia}
    \label{fig:registro}
\end{figure}

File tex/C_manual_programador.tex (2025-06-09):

\apendice{Manual del  programador.} 
\section{Estructura de directorios}
En este capítulo, se va a explicar la estructura de directorios situados en el \href{https://github.com/cva1003/TFG}{repositorio} de Github.
\begin{itemize}
    \item AplicaciónEscritorio: carpeta que contiene todo el código para la implementación de la interfaz.
    \begin{itemize}
        \item app.py: código de la interfaz.
        \item interfaz.kv: código con el que se ha diseñado la interfaz.
        \item Arduino.ino: código arduino con el que se pueden realizar mediciones sin necesidad de la interfaz.
        \item cifrar.py: código python para cifrar los documentos, este codigo tambien esta incluido en app.py para descifrar y cifrar los documentos al abrir y cerrar la interfaz.
    \end{itemize}
    \item Diseño: carpeta que contiene el diseño del mango
    \item Videos: carpeta que contiene videos que muestran el funcionamiento de los prototipos.
    \item img: carpeta que contiene todas las imágenes que se han utilizado para la realización del proyecto.
    \item tex: carpeta que contiene todos los capítulos de la memoria y anexos.
    \begin{itemize}
        \item 1\_introducción.tex: documento LaTeX en el que se realiza la descripción inicial del proyecto.
        \item 2\_objetivos.tex: documento LaTeX en el que se exponen objetivos principales del proyecto y personales.
        \item 3\_teoricos.tex: documento LaTeX que recoge los conceptos teóricos y el estado del arte.
        \item 4\_DicusiónClinica.tex: documento LaTeX que recoge la información clínica, seguridad y comparación con otros estudios.
        \item 5\_metodología.tex: documento LaTeX en el que se exponen las técnicas y herramientas utilizadas para la realización del proyecto.
        \item 6\_resultados.tex: documento LaTeX que recoge un resumen de los resultados del proyecto
        \item 7\_conclusión.tex: documento LaTeX en que se exponen las conclusiones que se han sacado en la realización del proyecto
        \item 8\_lineas\_futuras.tex: documento LaTeX que recoge las posibles líneas futuras que puede experimentar el proyecto.
        \item A\_planificación.tex: documento LaTeX en el que se expone la planificación temporal y económica y la viabilidad legal
        \item B\_manual\_usuario.tex: documento LaTeX que recogen aquellos requisitos necesarios para la ejecución y puesta en marcha del proyecto.
        \item C\_manual\_programador.tex: documento LaTeX que recoge la estructura de directioros del proyecto.
        \item D\_datos.tex: documento LaTeX que recoge la descripción de los datos recogidos.
        \item E\_diseño.tex: documento LaTeX que recoge los planos y el diseño del prototipo realizado.
        \item F\_requisitos.tex: documento LaTeX que incluye los casos de uso.
        \item G\_experimental.tex: documento LaTeX que detalla la configuración y parametrización de las técnicas utilizadas.
        \item H\_ODS.tex: documento LaTeX que incluye una reflexión personal sobre los aspectos de la sostenibilidad que se abordan en el proyecto.
    \end{itemize}
    \item Readme.md: archivo md (lenguaje de texto Mark Down) de presentación del proyecto en GitHub.
    \item Memoria\_Anexos\_PDF: Carpeta que contiene el documento de memoria y el de anexo en formato pdf.
    \begin{itemize}
        \item memoria.pdf: documento pdf con la memoria completa.
        \item anexo.pdf: documento pdf con el anexo completo.
    \end{itemize}
    \item anexo.tex: documento LaTeX que contiene la estructura del anexo.
    \item memoria.tex: documento LaTeX que contiene la estructura de la memoria.
    \item bibliografia.bib: documento que recoge toda la bibliografía empleada en la memoria.
    \item bibliografiaAnexos.bib: documento que recoge toda la bibliografía empleada en el anexo.
\end{itemize}
\section{Compilación, instalación y ejecución del proyecto}
Para la compilación y ejecución del proyecto es necesario: 
\begin{itemize}
    \item Instalación de Arduino IDE y Python.
    \item Una vez instalados abrir la consola CMD e instalar las bibliotecas necesarias, especificadas en el apartado 2 del anexo B. 
    \item A continuación, será necesario la descarga de los archivos de la carpeta AplicacionEscritorio del repositorio de GitHub. Abrir el archivo Arduino.ino en la aplicación Arduino IDE, conectar la placa arduino mediante el puerto USB al ordenador y enviar el archivo a la placa. 
    \item Para finalizar, abrir el CMD o una aplicación de editor de texto como Visual Studio Code, navegar hasta la localización de la carpeta y ejecutar python app.py .
\end{itemize}

\section{Instrucciones para la modificación o mejora del proyecto.}

Debido a que en la realización del proyecto se han realizado dos prototipos, el físico y el desplegable, se podrían implementar varias mejoras.

Si hablamos del dispositivo físico, se podría realizar un estudio con otros sensores de menor tamaño para que niños o personas con las manos más pequeñas pudieran utilizarlo correctamente. Así mismo, la implementación de resortes podría ser útil, ya que implica un esfuerzo extra para el paciente al aplicar una fuerza constante. 

En cuanto al desplegable, que fuera posible que se acceda al desplegable sin necesidad de tener que abrir el CMD del ordenador facilitaría su uso a los profesionales.

La configuración y parametrización de los sensores se podría mejorar utilizando una báscula profesional y aplicando una fuerza constante exacta, ya que debido a los materiales que se disponían este proceso ha sido más rudimentario.

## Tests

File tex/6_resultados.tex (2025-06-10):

\capitulo{6}{Resultados}

\section{Resumen de resultados}

Se presenta en este capítulo un resumen de los resultados obtenidos durante el desarrollo del proyecto. 
\begin{itemize}
    
    \item \textbf{Elección de un sensor capaz de medir la fuerza ejercida por cada dedo.}
    
    Se ha utilizado el sensor de fuerza resistivo MD30-60, ofreciendo resultados satisfactorios en las pruebas realizadas. Con el objetivo de lograr un ajuste de las medidas lo más cercano a la realidad, se realizó una calibración en los sensores, para más detalle véase el Apendice G.1 del anexo. Además se realizó un análisis del porcentaje de error, ofreciendo como resultado, un valor de error medio de 4.6\%, con valores de pico de hasta un 10\% error.
    
    \item \textbf{Creación de un prototipo de dispositivo que pueda medir la presión ejercida por la mano.}
    
    Se ha logrado la creación de un prototipo funcional del dispositivo (\ref{fig:Prototipo Fisico}), cumpliendo con el diseño inicial de medir la presión ejercida por cada dedo de la mano de forma orientativa y repetible. Este prototipo integra cinco sensores de fuerza resistivos, una placa de arduino, una placa de pruebas, una luz led, un pin botón y otros materiales complementarios como resistencias y cables, proporcionando un prototipo integral que cumple con los requisitos necesarios. 

    Adicionalmente, se ha diseñado un accesorio complementario (\ref{fig:Accesorio}) que facilita el uso del dispositivo durante sesiones de rehabilitación. Tiene una dimensión de 60x60x135, con un agujero interior para insertar una de las barras de la
    tabla canadiense y cinco hendiduras destinadas a situar cada uno de los sensores.

    \begin{figure}
        \centering
        
        \caption{Accesorio para tabla canadiense. Fuente propia}
        \label{fig:Accesorio}
    \end{figure}
    \begin{figure}
        \centering
        
        \caption{Prototipo físico. Fuente propia}
        \label{fig:Prototipo Fisico}
    \end{figure}
    \item \textbf{Seguimiento de evolución de los pacientes.}

    Se ha desarrollado un prototipo de interfaz tipo desplegable, capaz de almacenar los datos obtenidos por los sensores en un archivo xlsx. Además de su almacenamiento, permite al profesional la visualización de estos mediante una tabla (\ref{fig:tabla-registro}) o representando los datos mediante una gráfica (\ref{fig:Grafica-datos}). 
    
    La estructura y visualización de los datos recolectados se amplía en el Apéndice D del anexo.
    \begin{figure}
        \centering
        
        \caption{Representación datos en gráfica. Fuente propia}
        \label{fig:Grafica-datos}
    \end{figure}
    \begin{figure}
        \centering
        
        \caption{Tabla de registros. Fuente propia}
        \label{fig:tabla-registro}
    \end{figure}
    \item \textbf{Comparativa de prototipos}
    
    Tras la realización del proyecto, he realizado una comparativa con otros prototipos mencionados en la sección 'Estado del arte'.

    A pesar de que los 3 prototipos emplean los sensores resistivos y tienen como finalidad el seguimiento de los pacientes para facilitar la recuperación, existen algunas diferencias. 
    En la tabla \ref{tab:comparacion_diseños} se presenta una comparativa de los 3 dispositivos.
\end{itemize}

\begin{table}[h]
    \centering
    \begin{tabular}{|p{2.5cm}|p{3.5cm}|p{4cm}|p{3.8cm}|}
    \rowcolor[HTML]{BFBFBF} 
    \hline
    \textbf{Aspecto} & \textbf{Juliana Gómez et al.} & \textbf{Luis Carlos Ralón Gordill} & \textbf{Diseño propio} \\ \hline
    Sensor utilizado   & FSR  & FSR  & FSR \\ \hline
    Número de sensores   & 5  & 1  & 5 \\ \hline
    Uso del resorte & Transmisión de fuerza & Generar resistencia  & No aplica   \\ \hline
    Mecanismo de transmisión   & Mediante resorte  & Mediante resorte & Directo  \\ \hline
    Ventajas   & Alta precisión  & Uso en niños  & Uso aplicabilidad múltiple \\ \hline
    Limitaciones & Solo permite el agarre de precisión & Fallos en Resorte-Sensor & Error medio de 4.6\% \\ \hline
    Visualización & Interfaz, visualización en el momento & Interfaz gráfica, visualización en el momento& Interfaz desplegable, con posibilidad de ver registros anteriores \\ \hline
    Coste    & No menciona    & No menciona precio exacto, pero deja claro que busca producir el menos coste y al utilizar un único sensor el coste total es bajo. & 78€ \\ \hline
    \end{tabular}
    \caption{Comparación de los prototipos.}
    \label{tab:comparacion_diseños}
\end{table}
    
\section{Discusión}

Los resultados obtenidos cumplen con los objetivos marcados en el inicio del proyecto. Se ha logrado realizar un prototipo de interfaz y dispositivo capaz de registrar los datos recogidos por los sensores.

La implementación de los gráficos en la visualización de los registros permite una representación clara de la evolución de los pacientes durante las sesiones. Facilitando la interpretación de los datos recogidos por los profesionales sanitarios, detectando progresos, fatiga muscular o estancamientos, factores muy útiles en la toma de decisiones médicas.

Además, la protección de los datos es uno de los aspectos fundamentales en la creación del dispositivo. Se cumplen en todo momento mediante la encriptación de los documentos. El uso de bibliotecas para el cifrado se detalla en el Apéndice C.1 y D.1 del anexo.

Por último, destacar la utilización de materiales que impliquen el menor coste posible en la realización del dispositivo. El análisis económico detallado y la viabilidad legal se exponen en los Apéndices A.3 y A.4 del anexo.

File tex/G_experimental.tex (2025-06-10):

\apendice{Estudio experimental}
Durante la realización del proyecto, no se ha realizado un estudio experimental. 

La realización de este seria esencial en un futuro cuando se haya obtenido un dispositivo final antes de lanzarlo al mercado. 

Sería útil realizar un estudio con un conjunto de pacientes para hacer un seguimiento de los datos recogidos por el dispositivo y observar cómo evolucionan desde la primera sesión hasta que finalmente se les da de alta.
De esta manera, se podría observar si las sesiones están resultado positivas o, en caso contrario, determinar si deberían interrumpirse para que un nuevo paciente en lista de espera pueda acceder a las sesiones de terapia.

\section{Configuración y parametrización de las técnicas.}

Para una correcta cuantificación de la fuerza ejercida a los sensores se ha realizado una parametrización de los sensores de fuerza resistivos. 

Al emplear este tipo de sensores para medir, la relación entre el nivel de cuantificación y la magnitud del peso no se comporta de manera lineal, sino que la curva característica muestra un comportamiento exponencial o logarítmico. 

En este proceso, primero se ha hecho una relación entre 10 pesos y el valor leído por el sensor (véase tabla \ref{tab:Relación Valor-Peso}). 
\begin{table}[h]
    \centering
    \begin{tabular}{|c|c|}
    \rowcolor[HTML]{BFBFBF} 
        \hline
        \textbf{Valor} & \textbf{Peso (kg)} \\ \hline
        0   & 0    \\ \hline
        165 & 0.5  \\ \hline
        258 & 1    \\ \hline
        302 & 1.5  \\ \hline
        340 & 2    \\ \hline
        368 & 2.5  \\ \hline
        404 & 3    \\ \hline
        440 & 3.5  \\ \hline
        460 & 4    \\ \hline
        498 & 4.5  \\ \hline
   \end{tabular}
    \caption{Relación Valor-Peso}
    \label{tab:Relación Valor-Peso}
\end{table}
Dado que solo se han obtenido diez valores experimentales, los valores que se encuentren entre dos de estos se determinan mediante interpolación lineal, que sigue la siguiente fórmula:
\begin{equation}
    y = \frac{y_1 - y_0}{x_1 - x_0} \cdot (x - x_0) - y_0
    \label{eq: Interpolación lineal}
\end{equation}

Dado que utilizamos este tipo de ecuación, los resultados no son 100\% reales, pero sí aproximados.

En la figura \ref{fig:Grafica peso-valor} se puede observar cómo crece la curva que relaciona los valores medidos con los pesos. El crecimiento de los primeros valores es considerablemente más pronunciado en comparación con los valores obtenidos con pesos más altos, lo cual se debe al comportamiento característico de los sensores de fuerza resistivos. 
\begin{figure}
    \centering
    
    \caption{Gráfica peso-valor. Fuente propia}
    \label{fig:Grafica peso-valor}
\end{figure}

Dado que al medir la fuerza ejercida se pueden crear picos máximos o mínimos falsos, se ha implementado la fórmula de la desviación estándar.
\begin{equation}
    \sigma=\sqrt{\frac{\sum\left(x_{i}-\mu\right)^{2}}{N}}
\end{equation}
Donde sigma es la desviación estándar, mu es la media, xi es cada valor muestreado y N es el total muestreado.

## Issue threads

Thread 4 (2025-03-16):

Conceptos teoricos

cva1003, 2025-03-16:
Sección donde voy definiendo las palabras que me parecen importantes para la compresión del texto.

cva1003, 2025-03-16:
Estoy planteando estos conceptos segun avanzo en el trabajo

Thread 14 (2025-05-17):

Realizar codigo arduino

cva1003, 2025-05-17:
Realizado, es necesario implementarlo en la placa para despues utilizar el desplegable.
Se puede medir con este codigo sin necesidad de utilizar el desplegable

Closed 2025-05-17.

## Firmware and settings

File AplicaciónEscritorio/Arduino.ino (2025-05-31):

int pulgar=A0;
int indice=A1;
int corazon=A2;
int anular=A3;
int menique=A4;
int pinBoton=2;
int luz=4;
float deLecturaAPeso(int x){
  int lectura[]={};
  float peso[]={0,0.5,1.0,1.5,2.0,2.5,3.0,3.5,4.0,4.5};
  int n=10;
  if (x < lectura[0] || x > lectura[n-1]) return -1.0;  // Fuera de rango
  for (int i=0; i < n-1; i++) { // Función de interpolación lineal para 
                                //calcular pesos intermedios entre los ptos declarados.
    if (x >= lectura[i] && x <= lectura[i+1]) {
      float m=(peso[i+1]-peso[i]) / (lectura[i+1]-lectura[i]);
      return  m*(x-lectura[i])+peso[i];
      }
    }
    return -1.0;// Fuera de rango
}
void setup() {
  pinMode(pulgar,INPUT);
  pinMode(indice,INPUT);
  pinMode(corazon,INPUT);
  pinMode(anular,INPUT);
  pinMode(menique,INPUT);
  pinMode(pinBoton,INPUT);
  pinMode(luz,OUTPUT);
  Serial.begin(9600);
}
void loop() {
  if (digitalRead(pinBoton) == HIGH) {
    Serial.println("Empezando a medir");
    digitalWrite(luz, HIGH);
    int datosPulgar[numDatos];
    int datosIndice[numDatos];
    int datosCorazon[numDatos];
    int datosAnular[numDatos];
    int datosMenique[numDatos];
    for (int i = 0; i < numDatos; i++) {
      datosPulgar[i] = analogRead(pulgar);
      datosIndice[i] = analogRead(indice);
      datosCorazon[i] = analogRead(corazon);
      datosAnular[i] = analogRead(anular);
      datosMenique[i] = analogRead(menique);
      delay(500);
    }
    digitalWrite(luz, LOW);

    filtrado("Pulgar",datosPulgar,numDatos);
    filtrado("Indice",datosIndice,numDatos);
    filtrado("Corazon",datosCorazon,numDatos);
    filtrado("Anular",datosAnular,numDatos);
    filtrado("Menique",datosMenique,numDatos);
    delay(2000);
  } 
}

void filtrado(String nombre, int datos[], int total){
  float suma = 0;
  for (int i = 0; i < total; i++){
    suma += datos[i];
  }
  float media = suma/total;
  // Calcula desviación estandar para eliminar datos atipicos
  float sumaDesviacion = 0;
  for (int i = 0; i < total; i++){
    sumaDesviacion += pow(datos[i] - media, 2);
  }
  float desviacion = sqrt(sumaDesviacion/total);

  float limiteInferior = media - desviacion;
  float limiteSuperior = media + desviacion;

  float sumaFiltrada = 0;
  int contadorFiltrados = 0;

  for (int i = 0; i < total; i++){
    if (datos[i] >= limiteInferior && datos[i] <= limiteSuperior){
      sumaFiltrada += datos[i];
      contadorFiltrados++;
    }
  }
  float mediaFiltrada = (sumaFiltrada/contadorFiltrados);
  float kg = deLecturaAPeso(mediaFiltrada);

  Serial.print(nombre);
  Serial.print(": ");
  Serial.print(kg);
  Serial.print(" Kg | ");
}

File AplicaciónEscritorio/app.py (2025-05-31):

from datetime import datetime
import json
import os
import pandas as pd
import serial 
from kivy.app import App
from kivy.uix.screenmanager import Screen
from kivy.lang import Builder
from kivy.uix.popup import Popup
from kivy.uix.label import Label
from openpyxl import load_workbook
from kivy.metrics import dp
from kivymd.app import MDApp
from kivymd.uix.datatables import MDDataTable
import matplotlib.pyplot as plt
from kivy.uix.image import Image
from cryptography.fernet import Fernet

def cargar_clave():
    return open('clave.key', 'rb').read()

def encriptar(nom_archivo, clave):
    f = Fernet(clave)
    with open(nom_archivo, 'rb') as file:
        archivo_info = file.read()
    encrypted_data = f.encrypt(archivo_info)
    with open(nom_archivo, 'wb') as file:
        file.write(encrypted_data)

def desencriptar(nom_archivo, clave):
    f = Fernet(clave)
    with open(nom_archivo, 'rb') as file:
        encrypted_data = file.read()
    decrypted_data = f.decrypt(encrypted_data)
    with open(nom_archivo, 'wb') as file:
        file.write(decrypted_data)

clave = cargar_clave()
desencriptar("usuarios.json", clave)
desencriptar("registro_pacientes.xlsx", clave)

usuarios_registrados = "usuarios.json"

def guardar_usuarios(usuarios):
    with open(usuarios_registrados, "w") as f:
        json.dump(usuarios, f)

def cargar_usuarios():
    if os.path.exists(usuarios_registrados):
        with open(usuarios_registrados, "r") as f:
            contenido = f.read()
            if contenido.strip():
                return json.loads(contenido)
    return {}

usuarios = cargar_usuarios()

def mostrar_advertencia(mensaje):
    popup = Popup(
        title='ERROR',
        content=Label(text=mensaje),
        size_hint=(None, None),
        size=(400, 200))
    popup.open()

class PrincipalScreen(Screen):
    pass

class VisualizacionScreen(Screen):
    def actualizar_nombre(self, nombre_completo):
        self.ids.nombre_paciente_visualizacion.text = f' {nombre_completo.replace("_", " ") }'
        self.tabla(nombre_completo)
    def tabla(self, nombre_completo):
        nombre_apellidos = nombre_completo.split()
        if len(nombre_apellidos) > 3:
            nombre_con_guion = nombre_apellidos[1] + "_" + nombre_apellidos[2] + "_" + nombre_apellidos[3]
        else:
            nombre_con_guion = nombre_apellidos[1] + "_" + nombre_apellidos[2]
        nombre_hoja = nombre_con_guion
        DATA = pd.read_excel("registro_pacientes.xlsx", sheet_name=nombre_hoja)
        cols = DATA.columns.values
        values = DATA.values
        self.data_tables = MDDataTable(
            use_pagination=True,
            column_data=[(col, dp(30)) for col in cols],
            row_data=values)
        contenedor = self.ids.get("contenedor_tabla")
        contenedor.clear_widgets()
        contenedor.add_widget(self.data_tables)

class VisualizargraficaScreen(Screen):
    def actualizar_nombre(self, nombre_completo):
        self.ids.nombre_paciente_visualizacion.text = f' {nombre_completo.replace("_", " ") }'
        self.grafica(nombre_completo)
    def grafica(self, nombre_completo):
        nombre_apellidos = nombre_completo.split()
        if len(nombre_apellidos) > 3:
            nombre_con_guion = nombre_apellidos[1] + "_" + nombre_apellidos[2] + "_" + nombre_apellidos[3]
        else:
            nombre_con_guion = nombre_apellidos[1] + "_" + nombre_apellidos[2]
        nombre_hoja = nombre_con_guion
        df = pd.read_excel("registro_pacientes.xlsx", sheet_name=nombre_hoja)
        fecha = df['Fecha']
        dedos = ['Pulgar(Kg)','Indice(Kg)','Corazón(Kg)','Anular(Kg)','Meñique(Kg)']
        plt.figure(figsize=(10, 6))
        for dedo in dedos:
            plt.plot(fecha, df[dedo], marker='o', label=dedo)
        plt.title("Fuerza por dedo (Kg)")
        plt.xlabel("Fecha")
        plt.ylabel("Fuerza (Kg)")
        plt.legend()
        plt.grid(True)
        plt.tight_layout()
        plt.savefig("grafica_dedos.png")
        plt.close()
        contenedor = self.ids.contenedor_grafica
        contenedor.clear_widgets()
        imagen = Image()
        imagen.source = "grafica_dedos.png"
        imagen.reload()
        contenedor.add_widget(imagen)
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

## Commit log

2025-03-08 Creación del capitulo de Introducción
2025-03-25 Cambio en la introducción
2025-03-29 he añadido información de articulos
2025-04-14 Actualización de la información
2025-04-22 Prototipo1 mango para sensores
    [prototipo 1.FCStd]
2025-04-27 Codigo app de escritorio provisional
2025-04-30 Adicción de librerias e imagen sensor
2025-04-30 cambio en el prototipo del mango
    [prototipo 1.FCStd]
2025-05-12 Creacion fichero arduino
2025-05-14 prototipo 2 mango mejorado
    [prototipo 2 mango (6cm diametro).FCStd]
2025-05-17 Codigo arduino con el que se puede medir sin necesidad de abrir la interfaz
2025-05-19 Realización casos de usos y su explicación
2025-05-25 Cambio de punto
2025-05-26 Contexto de uso real y limitaciones y riesgos clinicos
2025-05-27 Se ha añadido una luz led para facilitar la visualización del tiempo de medición
2025-05-28 Actualización de precios
2025-05-31 Arduino con desviación estandar para filtrar resultados
2025-06-01 Finalización de capitulo D
2025-06-02 Realización anexo de sostenibilización curricular
2025-06-02 Imagenes usadas en la memoria
2025-06-02 Corrección de errores
2025-06-09 Archivo para cifrar y descifrar documentos.
2025-06-10 Archivos de memoria y anexo
